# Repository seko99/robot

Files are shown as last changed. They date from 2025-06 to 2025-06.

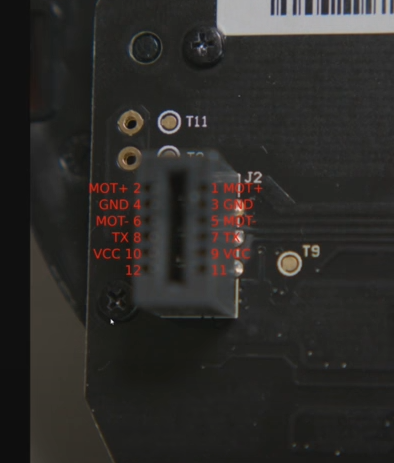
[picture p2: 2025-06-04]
docs/LDS01RR/2024-12-21_15-33.png

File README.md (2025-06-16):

# Robot Control System

Проект системы управления мобильным роботом с дифференциальным приводом на базе Arduino и Orange Pi Zero 3.

## 🤖 Описание

Это комплексная система управления роботом, состоящая из:

- **Arduino микроконтроллеры** для низкоуровневого управления моторами и сенсорами
- **Orange Pi Zero 3** как основной компьютер для высокоуровневой логики
- **ROS2 пакеты** для навигации и управления
- **Ультразвуковые датчики** для определения расстояний
- **Энкодеры** для одометрии
- **Лидар LDS01RR** для 2D сканирования окружения

## 📁 Структура проекта

```
robot/
├── Motors/           # Arduino код для управления моторами
│   ├── Motors.ino   # Основной код управления моторами
│   └── compile.sh   # Скрипт компиляции для Arduino
├── Sensors/          # Arduino код для работы с датчиками
│   ├── Sensors.ino  # Код для ультразвукового датчика
│   └── compile.sh   # Скрипт компиляции для Arduino
├── ROS2/            # ROS2 пакеты для управления роботом
│   ├── robot_bringup/      # Основной пакет запуска
│   ├── robot_odometry/     # Расчет одометрии
│   ├── robot_sonar/        # Обработка ультразвука
│   ├── robot_teleop/       # Телеуправление
│   ├── robot_lidar/ # Драйвер лидара LDS01RR
│   ├── install_packages.sh # Установка пакетов
│   ├── run_robot.sh        # Запуск системы
│   ├── upload_packages.sh  # Загрузка на робота
│   ├── build_on_robot.sh   # Сборка на роботе
│   ├── diagnose_packages.sh # Диагностика пакетов
│   ├── test_package.sh     # Тестирование пакетов
│   ├── PACKAGES_SUMMARY.md # Описание пакетов
│   └── requirements.txt    # Python зависимости
├── 3dprint/         # 3D модели креплений и корпуса (FreeCAD .FCStd)
├── docs/            # Документация и схемы
│   ├── LDS01RR/     # Документация лидара
│   └── *.pdf        # Схемы Orange Pi Zero 3
├── motor_test.py    # Скрипт тестирования моторов
├── serial_read.py   # Утилита чтения Serial данных
├── compile.sh       # Основной скрипт компиляции и загрузки
└── upload_py.sh     # Загрузка Python скриптов
```

## 🐳 Docker контейнеризация

Каждый ROS2 пакет упакован в отдельный Docker контейнер для обеспечения:

- **Изоляции зависимостей** - каждый пакет работает в своем окружении
- **Простоты развертывания** - один команда для запуска
- **Портабильности** - работает на любой системе с Docker
- **Масштабируемости** - легко добавить новые контейнеры

### Особенности реализации

- **Entrypoint скрипты** - корректная инициализация ROS2 окружения в контейнерах
- **Управление устройствами** - проброс USB портов для Serial связи
- **Сетевое взаимодействие** - режим host для DDS коммуникации между контейнерами
- **Автоматическая сборка** - Dockerfile для каждого пакета

## 🔧 Компоненты системы

### Arduino модули

#### Motors (Управление моторами)

- **Файл**: `Motors/Motors.ino`
- **Функции**:
  - Управление двумя DC моторами через драйвер TB6612FNG
  - Чтение энкодеров для одометрии
  - Обработка команд по Serial
- **Пины**:
  - Левый мотор: IN1=5, IN2=6, ENA=9
  - Правый мотор: IN3=7, IN4=8, ENB=10
  - Энкодеры: LEFT_H1=4, LEFT_H2=12, RIGHT_H1=2, RIGHT_H2=3

#### Sensors (Датчики)

- **Файл**: `Sensors/Sensors.ino`
- **Функции**:
  - Ультразвуковой датчик HC-SR04
  - Передача данных о расстояниях
- **Пины**:
  - TRIG=9, ECHO=10

### ROS2 пакеты

Полноценные ROS2 пакеты для автономного управления с поддержкой Docker:

#### 📦 robot_bringup

Основной пакет для запуска всех компонентов робота

#### 📦 robot_odometry

Расчет одометрии на основе данных энкодеров

- **Топики**: `/odom` (nav_msgs/Odometry)
- **Конфигурация**: `config/odometry_params.yaml`
- **Docker**: Собственный контейнер с entrypoint скриптом

#### 📦 robot_sonar

Обработка данных ультразвукового датчика

- **Топики**: `/ultrasonic_sensor/range` (sensor_msgs/Range)
- **Конфигурация**: `config/sonar_params.yaml`
- **Docker**: Собственный контейнер с entrypoint скриптом

#### 📦 robot_teleop

Телеуправление роботом с клавиатуры

- **Подписка**: `/cmd_vel` (geometry_msgs/Twist)
- **Конфигурация**: `config/teleop_params.yaml`
- **Docker**: Собственный контейнер с entrypoint скриптом

#### 📦 robot_lidar

Драйвер для лидара LDS01RR

- **Топики**: `/scan` (sensor_msgs/LaserScan)
- **Функции**: 2D лазерное сканирование для навигации
- **Docker**: Собственный контейнер с entrypoint скриптом

## 🚀 Быстрый старт

### Нативная установка ROS2 пакетов

```bash
cd ROS2/
./install_packages.sh
```

### Запуск через Docker

Каждый ROS2 пакет имеет собственный Docker контейнер для изолированного запуска:

```bash
# Сборка Docker образов для всех пакетов
cd ROS2/robot_teleop/
docker build -t robot_teleop .

cd ../robot_sonar/
docker build -t robot_sonar .

cd ../robot_odometry/
docker build -t robot_odometry .

cd ../robot_lidar/
docker build -t robot_lidar .

# Запуск отдельных пакетов в контейнерах
docker run --rm --device=/dev/ttyUSB0 robot_teleop
docker run --rm --device=/dev/ttyUSB1 robot_sonar
docker run --rm --device=/dev/ttyUSB0 robot_odometry
docker run --rm --device=/dev/ttyUSB2 robot_lidar

# Запуск с сетевым режимом host для ROS2 DDS
docker run --rm --network host --device=/dev/ttyUSB0 robot_teleop
```

### pyhton3 зависимости

```bash
sudo apt install python3-pip
sudo apt install python3-serial
```

### Запуск системы (нативно)

```bash
# Полный запуск всех компонентов
./run_robot.sh full

# Управление с клавиатуры
./run_robot.sh keyboard

# Только одометрия
./run_robot.sh odometry

# С лидаром
./run_robot.sh lidar
```

### Сборка и загрузка на робота

```bash
# Установка пакетов на удаленного робота
cd ROS2/
./upload_packages.sh

# Сборка на роботе
./build_on_robot.sh

# Удаленный запуск
ssh -i ~/.ssh/id_rsa orangepi@192.168.2.141 'cd ~/ros2_ws && ./run_robot.sh full'
```

### Компиляция Arduino кода

#### arduino-cli

```bash
wget https://downloads.arduino.cc/arduino-cli/arduino-cli_latest_Linux_ARM64.tar.gz
tar -xf arduino-cli_latest_Linux_ARM64.tar.gz
sudo mv arduino-cli /usr/local/bin/

/usr/local/bin/arduino-cli version

arduino-cli core update-index
arduino-cli core install arduino:avr

```

```bash
# Основной скрипт (компиляция и загрузка)
./compile.sh

# Для моторов отдельно
cd Motors/
./compile.sh

# Для датчиков отдельно
cd Sensors/
./compile.sh
```

## 🛠 Настройка оборудования

### Подключение Arduino

- **Motors Arduino**: подключить к Orange Pi через USB (/dev/ttyUSB0)
- **Sensors Arduino**: подключить к Orange Pi через USB (/dev/ttyUSB1)
- Настроить правильные порты в ROS2 конфигурации

### Подключение лидара LDS01RR

- **Питание**: 5V
- **Интерфейс**: Serial (115200 baud)
- **Подключение**: к Orange Pi через USB-Serial конвертер

### Схема подключения моторов

```
TB6612FNG драйвер:
- STBY -> Pin 11
- Левый мотор: AIN1->5, AIN2->6, PWMA->9
- Правый мотор: BIN1->7, BIN2->8, PWMB->10
- Энкодеры: подключить к цифровым пинам с прерываниями
```

### Датчики

```
HC-SR04:
- VCC -> 5V
- GND -> GND
- Trig -> Pin 9
- Echo -> Pin 10
```

## 📡 Протокол связи

### Команды для моторов

- `CMD_LEFT_FORWARD (0)` - левый мотор вперед
- `CMD_LEFT_BACKWARD (1)` - левый мотор назад
- `CMD_RIGHT_FORWARD (2)` - правый мотор вперед
- `CMD_RIGHT_BACKWARD (3)` - правый мотор назад
- `CMD_STOP_MOTORS (6)` - остановка всех моторов

### Структуры данных

```cpp
struct Command {
  uint8_t cmd;
  uint8_t value;  // скорость 0-255
};

struct SensorData {
  uint32_t timestamp;
  float left_odometry;
  float right_odometry;
  // ... дополнительные поля
};
```

## 🧪 Тестирование

### Тест моторов

```bash
python3 motor_test.py
```

### Чтение Serial данных

```bash
python3 serial_read.py
```

### Диагностика ROS2

```bash
cd ROS2/
./diagnose_packages.sh
./test_package.sh
```

### Телеуправление

```bash
# Через ROS2 пакет
cd ROS2/
./run_robot.sh keyboard

# Или стандартный teleop_twist_keyboard
ros2 run teleop_twist_keyboard teleop_twist_keyboard
```

### Мониторинг данных

```bash
# Одометрия
ros2 topic echo /odom

# Ультразвук
ros2 topic echo /ultrasonic_sensor/range

# Лидар
ros2 topic echo /scan

# Команды управления
ros2 topic echo /cmd_vel
```

## 📋 Требования

### Программное обеспечение

- **Arduino IDE** или **arduino-cli**
- **ROS2 Jazzy** (на Orange Pi) или **Docker**
- **Python 3.8+**
- **pyserial** для Python скриптов
- **colcon** для сборки ROS2 пакетов (при нативной установке)
- **Docker** (для контейнерного развертывания)

### Аппаратное обеспечение

- **Orange Pi Zero 3** (основной компьютер)
- **Arduino Uno/Nano** x2 (моторы и датчики)
- **TB6612FNG** (драйвер моторов)
- **HC-SR04** (ультразвуковой датчик)
- **LDS01RR** (лидар для 2D сканирования)
- **DC моторы с энкодерами** x2
- **Аккумулятор** и **DC-DC конвертер**

## 🔍 Отладка

### Проверка подключения

```bash
# Список доступных портов
ls /dev/ttyUSB* /dev/ttyACM*

# Тест связи
python3 serial_read.py

# Проверка ROS2 пакетов
ros2 pkg list | grep robot
```

### Логи ROS2

```bash
# Проверка топиков
ros2 topic list

# Мониторинг данных
ros2 topic echo /odom
ros2 topic echo /scan
ros2 topic echo /ultrasonic_sensor/range

# Отправка команд управления
ros2 topic pub /cmd_vel geometry_msgs/msg/Twist \
  "{linear: {x: 0.1}, angular: {z: 0.0}}" --once
```

### Диагностика компонентов

```bash
# Проверка лидара
cd ROS2/robot_lidar/
python3 test_driver.py

# Диагностика всех пакетов
cd ROS2/
./diagnose_packages.sh
```

## 📄 Документация

### 3D модели (`3dprint/`)

В папке содержатся 3D модели компонентов робота в формате **FreeCAD (.FCStd)**:

- Крепления для зарядного устройства
- Крепления для DC-DC конвертера
- Крепления для повербанка
- Крепления для драйвера моторов TB6612FNG
- Крепления для аккумулятора
- Крепления для колес
- Крепление заднего колеса
- Пластина управления питанием
- Стойки 65мм

### Техническая документация (`docs/`)

Дополнительная документация и схемы:

- **Лидар LDS01RR**: datasheet, SDK, примеры ROS интеграции
- **Orange Pi Zero 3**: руководство пользователя и схемы
- Схемы подключения и фотографии сборки

## 🌐 Сетевая настройка

### Cyclone DDS

```bash
sudo apt install ros-jazzy-rmw-cyclonedds-cpp
export RMW_IMPLEMENTATION=rmw_cyclonedx_cpp
echo "export RMW_IMPLEMENTATION=rmw_cyclonedx_cpp" >> ~/.bashrc
```

#### Проверка

##### host1

```bash
sudo apt install ros-jazzy-demo-nodes-cpp
ros2 run demo_nodes_cpp listener
```

##### host2

```bash
sudo apt install ros-jazzy-demo-nodes-cpp
ros2 run demo_nodes_cpp talker
```

### SSH подключение

```bash
# Подключение к роботу
ssh -i ~/.ssh/id_rsa orangepi@192.168.2.141

# Загрузка файлов
scp -i ~/.ssh/id_rsa file.py orangepi@192.168.2.141:~
```

## SLAM

#### Установка

```bash
sudo apt install ros-jazzy-slam-toolbox
```

#### Настройка

Поменять в **/opt/ros/jazzy/share/slam_toolbox/config/mapper_params_online_async.yaml**:

```
base_frame: base_link
```

#### Граф

```bash
ros2 run tf2_tools view_frames
```

#### Запуск

```bash
ros2 launch slam_toolbox online_async_launch.py use_sim_time:=false
```

## Камера

#### Установка

```bash
sudo apt install ros-jazzy-usb-cam
```

#### На роботе

```bash
ros2 run usb_cam usb_cam_node_exe --ros-args -p video_device:="/dev/video1" -p pixel_format:="yuyv"
```

#### На GUI

```bash
ros2 run rqt_image_view rqt_image_view --ros-args -r image:=/image_raw
```

## Удаленное управление

```bash
# Запуск робота
ssh -i ~/.ssh/id_rsa orangepi@192.168.2.141 'cd ~/ros2_ws && ./run_robot.sh full'

# Загрузка пакетов на робота
cd ROS2/
./upload_packages.sh
```

## 🤝 Разработка

### Структура команд

Все команды используют бинарный протокол через Serial (115200 baud).

### Добавление новых сенсоров

1. Добавить код в `Sensors/Sensors.ino`
2. Создать соответствующий ROS2 пакет в `ROS2/`
3. Обновить launch файлы
4. Добавить в `run_robot.sh`

### Создание новых ROS2 пакетов

```bash
cd ROS2/
# Создание нового пакета
ros2 pkg create --build-type ament_python robot_new_package

# Установка
./install_packages.sh
```

## 🚀 Возможности системы

### Автономная навигация

- Одометрия на основе энкодеров
- 2D SLAM с использованием лидара LDS01RR
- Избегание препятствий через ультразвук
- Планирование пути

### Дистанционное управление

- Телеуправление через ROS2 топики
- SSH доступ для удаленной отладки
- Мониторинг состояния в реальном времени

### Модульная архитектура

- Независимые ROS2 пакеты
- Гибкая конфигурация через YAML файлы
- Простое добавление новых сенсоров

## 📞 Поддержка

При возникновении проблем:

1. Проверьте подключение всех компонентов
2. Убедитесь в правильности настройки портов
3. Используйте diagnostic скрипты для проверки ROS2
4. Проверьте логи: `ros2 topic echo /diagnostics`

### Частые проблемы

- **Нет данных с Arduino**: Проверить порты в конфигурации
- **Лидар не работает**: Проверить питание и скорость передачи
- **ROS2 пакеты не найдены**: Выполнить `source install/setup.bash`

---

**Автор**: seko  
**Дата**: 2025  
**Лицензия**: MIT

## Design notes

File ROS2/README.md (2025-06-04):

# ROS2 Robot Control Nodes

Этот проект содержит как отдельные ROS2 ноды, так и полноценные ROS2 пакеты для управления роботом с дифференциальным приводом.

## 🆕 ROS2 Пакеты (рекомендуется)

Новые готовые к установке ROS2 пакеты:

### Быстрая установка и запуск
```bash
# Установка всех пакетов
./install_packages.sh

# Запуск всех компонентов
./run_robot.sh full

# Управление с клавиатуры
./run_robot.sh keyboard
```

### Пакеты
- **robot_odometry** - Пакет одометрии с launch файлами и конфигурацией
- **robot_teleop** - Пакет телеуправления с launch файлами и конфигурацией  
- **robot_sonar** - Пакет сонара с launch файлами и конфигурацией
- **robot_bringup** - Пакет для запуска всех компонентов одной командой

---

## Отдельные ноды (legacy)

Этот пакет содержит ROS2 ноды для управления роботом с дифференциальным приводом.

### Компоненты

- **teleop.py** - Нода для телеуправления роботом через топик `/cmd_vel`
- **odom.py** - Нода для публикации одометрии в топик `/odom`
- **sonar_reader.py** - Нода для чтения данных с ультразвукового датчика

### Способы запуска

#### 1. Быстрый запуск (рекомендуется)

```bash
# Запуск с портами по умолчанию
./start_robot.sh

# Запуск с указанием портов
./start_robot.sh -m /dev/ttyACM0 -s /dev/ttyACM1

# Справка
./start_robot.sh --help
```

#### 2. Простой bash скрипт

```bash
./nodes_start.sh
```

#### 3. ROS2 Launch файлы

```bash
# Простой launch
ros2 launch simple_launch.py

# Полный launch с параметрами
ros2 launch robot_launch.py serial_port:=/dev/ttyUSB0 sonar_port:=/dev/ttyUSB1
```

#### 4. Ручной запуск отдельных нод

```bash
# В отдельных терминалах
python3 teleop.py
python3 odom.py  
python3 sonar_reader.py
```

### Параметры

#### teleop.py
- `serial_port` - Порт для подключения к Arduino моторов (по умолчанию: `/dev/ttyUSB0`)
- `baud_rate` - Скорость передачи данных (по умолчанию: `115200`)
- `max_linear` - Максимальная линейная скорость м/с (по умолчанию: `0.5`)
- `max_angular` - Максимальная угловая скорость рад/с (по умолчанию: `1.57`)
- `wheel_base` - Расстояние между колесами в метрах (по умолчанию: `0.3`)
- `max_motor_speed` - Максимальная скорость мотора PWM (по умолчанию: `255`)

#### odom.py
- `serial_port` - Порт для подключения к Arduino моторов (по умолчанию: `/dev/ttyUSB0`)
- `baud_rate` - Скорость передачи данных (по умолчанию: `115200`)
- `wheel_base` - Расстояние между колесами в метрах (по умолчанию: `0.3`)

#### sonar_reader.py
- `serial_port` - Порт для подключения к Arduino датчиков (по умолчанию: `/dev/ttyUSB1`)

### Топики ROS2

#### Подписка
- `/cmd_vel` (geometry_msgs/Twist) - Команды управления скоростью

#### Публикация
- `/odom` (nav_msgs/Odometry) - Данные одометрии
- `/ultrasonic_sensor/range` (sensor_msgs/Range) - Данные ультразвукового датчика

#### TF фреймы
- `odom` -> `base_link` - Трансформация одометрии

### Зависимости

#### Python пакеты
```bash
pip3 install pyserial
```

#### ROS2 пакеты
- rclpy
- geometry_msgs
- nav_msgs
- sensor_msgs
- tf2_ros

## Аппаратное обеспечение

- Arduino с загруженной прошивкой для моторов (Motors.ino)
- Arduino с загруженной прошивкой для датчиков (Sensors.ino)
- Энкодеры на моторах
- Ультразвуковой датчик

## Устранение неполадок

### Проблемы с портами
1. Проверьте подключение устройств: `ls /dev/tty*`
2. Проверьте права доступа: `sudo usermod -a -G dialout $USER`
3. Перезагрузитесь после добавления в группу

### Проблемы с ROS2
1. Убедитесь что ROS2 установлен: `ros2 --version`
2. Источник environment: `source /opt/ros/humble/setup.bash`

### Отладка
- Увеличьте уровень логирования: `export RCUTILS_LOGGING_SEVERITY=DEBUG`
- Проверьте топики: `ros2 topic list`
- Смотрите данные: `ros2 topic echo /odom`

## Мониторинг

```bash
# Просмотр топиков
ros2 topic list

# Чтение данных одометрии
ros2 topic echo /odom

# Чтение данных сонара
ros2 topic echo /ultrasonic_sensor/range

# Отправка команд движения
ros2 topic pub /cmd_vel geometry_msgs/Twist '{linear: {x: 0.1}, angular: {z: 0.1}}'

# Просмотр TF дерева
ros2 run tf2_tools view_frames
```

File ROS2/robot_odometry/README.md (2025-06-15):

# Robot Odometry Package

ROS2 пакет для публикации одометрии робота и управления движением с интегрированным телеуправлением.

## Описание

Этот пакет объединяет две основные функции:

1. Считывает данные одометрии с Arduino через последовательный порт
2. Обрабатывает команды телеуправления для управления моторами

Интеграция позволяет избежать конфликтов доступа к одному серийному порту.

## Установка

```bash
cd ~/ros2_ws/src
# Скопируйте пакет robot_odometry в src
cd ~/ros2_ws
colcon build --packages-select robot_odometry
source install/setup.bash
```

## Использование

```bash
# Запуск ноды одометрии с интегрированным teleop
ros2 run robot_odometry odometry_node

# Запуск с launch файлом
ros2 launch robot_odometry odometry.launch.py

# Просмотр топиков одометрии
ros2 topic echo /odom

# Отправка команд управления
ros2 topic pub /cmd_vel geometry_msgs/msg/Twist \
  "{linear: {x: 0.1, y: 0.0, z: 0.0}, angular: {x: 0.0, y: 0.0, z: 0.0}}"

# Запуск в режиме симуляции
ros2 run robot_odometry odometry_node --ros-args -p simulation_mode:=true
```

## Параметры

- `serial_port`: Порт Arduino (по умолчанию: /dev/ttyUSB0)
- `baud_rate`: Скорость передачи данных (по умолчанию: 115200)
- `wheel_base`: Расстояние между колесами в метрах (по умолчанию: 0.3)
- `max_linear`: Максимальная линейная скорость в м/с (по умолчанию: 0.5)
- `max_angular`: Максимальная угловая скорость в рад/с (по умолчанию: 1.57)
- `max_motor_speed`: Максимальная скорость мотора PWM (по умолчанию: 255)
- `simulation_mode`: Режим симуляции без подключения к Arduino (по умолчанию: false)

## Топики

### Публикуемые

- `/odom` (nav_msgs/Odometry): Информация об одометрии робота

### Подписываемые

- `/cmd_vel` (geometry_msgs/Twist): Команды управления движением

### TF Frames

- `odom` -> `base_link`: Трансформация положения робота

## Новая архитектура

В обновленной версии функциональность телеуправления интегрирована в одну ноду с одометрией для устранения конфликтов доступа к серийному порту. Это позволяет использовать один Arduino для обеих задач.

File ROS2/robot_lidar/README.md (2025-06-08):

# LDS01RR Lidar ROS2 Driver

ROS2 драйвер для лидара LDS01RR, переписанный с C++ на Python.

## Установка

### Предварительные требования

- ROS2 (Humble/Iron/Jazzy)
- Python 3.8+
- pyserial

### Установка зависимостей

```bash
# Установка Python зависимостей
pip install -r requirements.txt

# Или через apt (Ubuntu)
sudo apt install python3-serial
```

### Сборка и установка пакета

```bash
# Перейти в workspace
cd ~/ros2_ws/src

# Скопировать пакет
cp -r /path/to/lds01rr_lidar_ros2 .

# Собрать пакет
cd ~/ros2_ws
colcon build --packages-select lds01rr_lidar_ros2

# Источник среды
source install/setup.bash
```

## Использование

### Запуск драйвера

```bash
# Базовый запуск
ros2 run lds01rr_lidar_ros2 lidar_node

# Запуск с кастомными параметрами
ros2 run lds01rr_lidar_ros2 lidar_node --ros-args -p port:=/dev/ttyUSB0 -p baud_rate:=115200

# Запуск через launch файл
ros2 launch lds01rr_lidar_ros2 lidar_launch.py

# Запуск с кастомными параметрами через launch
ros2 launch lds01rr_lidar_ros2 lidar_launch.py port:=/dev/ttyUSB0 baud_rate:=115200
```

### Параметры

| Параметр | Тип | По умолчанию | Описание |
| --- | --- | --- | --- |
| `port` | string | `/dev/ttyACM0` | Серийный порт лидара |
| `baud_rate` | int | `115200` | Скорость порта |
| `frame_id` | string | `lidar` | Frame ID для данных лидара  |
| `publish_tf` | bool | `true` | Публиковать ли TF трансформ |
| `parent_frame` | string | `base_link` | Родительский frame для TF |

### Топики

#### Публикуемые топики

- `/scan` (`sensor_msgs/LaserScan`): Данные лазерного сканирования

#### TF Transforms

- `base_link` → `lidar` (если `publish_tf` == true)

## Настройка прав доступа к порту

```bash
# Добавить пользователя в группу dialout
sudo usermod -a -G dialout $USER

# Или установить права на конкретный порт
sudo chmod 666 /dev/ttyACM0
```

## Устранение неполадок

### Ошибка подключения к порту

1. Проверьте, что устройство подключено:

   ```bash
   ls /dev/ttyACM* /dev/ttyUSB*
   ```

2. Проверьте права доступа:

   ```bash
   ls -l /dev/ttyACM0
   ```

3. Проверьте, что порт не используется другим процессом:
   ```bash
   sudo lsof /dev/ttyACM0
   ```

### Нет данных от лидара

1. Проверьте параметры порта (скорость, порт)
2. Проверьте питание лидара
3. Проверьте логи ноды:
   ```bash
   ros2 run lds01rr_lidar_ros2 lidar_node --ros-args --log-level debug
   ```

## Визуализация

```bash
# Запуск RViz2
rviz2

# Добавить LaserScan display
# Topic: /scan
# Fixed Frame: lidar
```

## Лицензия

BSD-3-Clause

## Авторы

- Оригинальный C++ код: Eric Perko, Chad Rockey, iliasam
- Python порт для ROS2: Your Name

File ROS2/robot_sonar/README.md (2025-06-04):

# Robot Sonar Package

ROS2 пакет для чтения данных с ультразвукового датчика через Arduino.

## Описание

Этот пакет считывает данные с ультразвукового датчика через Arduino и публикует их в стандартном формате ROS2 `sensor_msgs/Range`.

## Установка

```bash
cd ~/ros2_ws/src
# Скопируйте пакет robot_sonar в src
cd ~/ros2_ws
colcon build --packages-select robot_sonar
source install/setup.bash
```

## Использование

```bash
# Запуск ноды сонара
ros2 run robot_sonar sonar_node

# Запуск с launch файлом
ros2 launch robot_sonar sonar.launch.py

# Просмотр данных сонара
ros2 topic echo /ultrasonic_sensor/range

# Просмотр частоты публикации
ros2 topic hz /ultrasonic_sensor/range
```

## Параметры

- `serial_port`: Порт Arduino (по умолчанию: /dev/ttyUSB1)
- `baud_rate`: Скорость передачи данных (по умолчанию: 115200)
- `frame_id`: ID фрейма для датчика (по умолчанию: sonar_link)
- `min_range`: Минимальная дальность в метрах (по умолчанию: 0.02)
- `max_range`: Максимальная дальность в метрах (по умолчанию: 4.0)
- `field_of_view`: Угол обзора в радианах (по умолчанию: 0.1)
- `publish_rate`: Частота публикации в Гц (по умолчанию: 10.0)

## Топики

### Публикуемые
- `/ultrasonic_sensor/range` (sensor_msgs/Range): Данные ультразвукового датчика

## Формат данных

Пакет ожидает бинарные данные от Arduino в формате:
- `uint8_t cmd`: Команда (обычно не используется)
- `float distance`: Расстояние в сантиметрах

## Обработка данных

- Данные автоматически преобразуются из сантиметров в метры
- Измерения вне диапазона обрабатываются специальным образом:
  - Слишком близкие: устанавливается значение меньше min_range
  - Слишком далекие: устанавливается infinity

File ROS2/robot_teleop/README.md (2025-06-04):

# Robot Teleop Package

ROS2 пакет для телеуправления роботом через Arduino.

## Описание

Этот пакет принимает команды управления через топик `/cmd_vel` и отправляет соответствующие команды на Arduino для управления моторами робота.

## Установка

```bash
cd ~/ros2_ws/src
# Скопируйте пакет robot_teleop в src
cd ~/ros2_ws
colcon build --packages-select robot_teleop
source install/setup.bash
```

## Использование

```bash
# Запуск ноды телеуправления
ros2 run robot_teleop teleop_node

# Запуск с launch файлом
ros2 launch robot_teleop teleop.launch.py

# Отправка команд управления
ros2 topic pub /cmd_vel geometry_msgs/msg/Twist "{linear: {x: 0.1, y: 0.0, z: 0.0}, angular: {x: 0.0, y: 0.0, z: 0.0}}"

# Использование с клавиатурой (требует установки teleop_twist_keyboard)
ros2 run teleop_twist_keyboard teleop_twist_keyboard
```

## Параметры

- `serial_port`: Порт Arduino (по умолчанию: /dev/ttyUSB0)
- `baud_rate`: Скорость передачи данных (по умолчанию: 115200)
- `max_linear`: Максимальная линейная скорость в м/с (по умолчанию: 0.5)
- `max_angular`: Максимальная угловая скорость в рад/с (по умолчанию: 1.57)
- `wheel_base`: Расстояние между колесами в метрах (по умолчанию: 0.3)
- `max_motor_speed`: Максимальное значение PWM для моторов (по умолчанию: 255)

## Топики

### Подписывается на
- `/cmd_vel` (geometry_msgs/Twist): Команды управления скоростью

## Команды моторов

Пакет отправляет бинарные команды на Arduino:
- `CMD_LEFT_FORWARD` (0): Левый мотор вперед
- `CMD_LEFT_BACKWARD` (1): Левый мотор назад
- `CMD_RIGHT_FORWARD` (2): Правый мотор вперед
- `CMD_RIGHT_BACKWARD` (3): Правый мотор назад
- `CMD_LEFT_STOP` (4): Остановка левого мотора
- `CMD_RIGHT_STOP` (5): Остановка правого мотора
- `CMD_STOP_MOTORS` (6): Остановка всех моторов

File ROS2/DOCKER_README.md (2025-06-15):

# Docker контейнеры для ROS2 нод робота

Этот проект содержит Docker контейнеры для всех ROS2 нод робота с поддержкой ROS2 Jazzy.

## Структура

- `robot_sonar/Dockerfile` - контейнер для ультразвукового сенсора
- `robot_odometry/Dockerfile` - контейнер для одометрии
- `robot_teleop/Dockerfile` - контейнер для телеуправления
- `robot_lidar/Dockerfile` - контейнер для лидара
- `docker-compose.yml` - полная конфигурация со всеми сервисами
- `docker-compose.robot.yml` - упрощенная конфигурация только для основных нод
- `docker-compose.discovery.yml` - конфигурация с ROS Discovery Server для более надежной сетевой связи

## Настройка сети

Для обеспечения видимости ROS2 нод между разными компьютерами в сети:

### 1. Настройка переменных окружения

```bash
# Создайте файл .env в директории ROS2
cp env.example .env

# Отредактируйте .env файл:
# - Установите одинаковый ROS_DOMAIN_ID на всех машинах
# - Укажите IP адрес робота в ROBOT_IP
```

### 2. Настройка на локальной машине (для RViz)

На вашей локальной машине установите те же переменные окружения:

**Вариант A: С CycloneDX (по умолчанию)**

```bash
export ROS_DOMAIN_ID=0  # Тот же, что и на роботе
export RMW_IMPLEMENTATION=rmw_cyclonedx_cpp
export CYCLONEDX_URI='<Discovery><Peers><Peer address="localhost"/><Peer address="192.168.1.100"/></Peers></Discovery>'
export ROS_LOCALHOST_ONLY=0
```

**Вариант B: С Discovery Server (более надежно)**

```bash
export ROS_DOMAIN_ID=0
export RMW_IMPLEMENTATION=rmw_fastrtps_cpp
export ROS_DISCOVERY_SERVER=192.168.1.100:11811  # IP робота
export ROS_LOCALHOST_ONLY=0
```

## Использование

### Запуск всех нод робота (основной режим)

```bash
cd ROS2
# Убедитесь, что .env файл настроен правильно
docker-compose -f docker-compose.robot.yml up -d
```

### Запуск с Discovery Server (рекомендуется для сетевого использования)

```bash
cd ROS2
# Для более надежной сетевой связи
docker-compose -f docker-compose.discovery.yml up -d
```

### Запуск всех нод включая GUI (для разработки)

```bash
cd ROS2
docker-compose up -d
```

### Запуск отдельных нод

```bash
# Только сонар
docker-compose -f docker-compose.robot.yml up robot-sonar

# Только лидар
docker-compose -f docker-compose.robot.yml up lidar

# Только одометрия
docker-compose -f docker-compose.robot.yml up robot-odometry
```

### Остановка всех контейнеров

```bash
docker-compose -f docker-compose.robot.yml down
```

### Просмотр логов

```bash
# Все логи
docker-compose -f docker-compose.robot.yml logs -f

# Логи конкретного сервиса
docker-compose -f docker-compose.robot.yml logs -f robot-sonar
```

## Особенности

### Доступ к устройствам

Все контейнеры имеют доступ к последовательным портам:

- `/dev/ttyUSB0`, `/dev/ttyUSB1`, `/dev/ttyUSB2`, `/dev/ttyUSB3`
- `/dev/ttyACM0`, `/dev/ttyACM1`

### Привилегированный режим

Контейнеры запускаются в привилегированном режиме (`privileged: true`) для обеспечения доступа к устройствам.

### Сеть

Используется `network_mode: host` для обеспечения ROS2 DDS коммуникации между контейнерами.

### Переменные окружения

- `ROS_DOMAIN_ID=0` - домен ROS2 по умолчанию

## Построение образов

Образы строятся автоматически при первом запуске. Для принудительной пересборки:

```bash
docker-compose -f docker-compose.robot.yml build
```

## Отладка

### Вход в контейнер

```bash
docker exec -it robot-sonar bash
```

### Проверка ROS2 нод

```bash
# Список активных нод
docker exec -it robot-sonar ros2 node list

# Список топиков
docker exec -it robot-sonar ros2 topic list

# Просмотр сообщений
docker exec -it robot-sonar ros2 topic echo /ultrasonic_sensor/range
```

### Проверка сетевого соединения

```bash
# На роботе - проверить активные ноды
docker exec -it lidar ros2 node list

# На локальной машине - проверить видимость удаленных нод
ros2 node list

# Проверить топики лидара с локальной машины
ros2 topic list | grep scan
ros2 topic echo /scan

# Запуск RViz на локальной машине
rviz2
```

### Устранение проблем с сетью

Если ноды не видны между машинами:

1. **Проверьте сетевое соединение:**

   ```bash
   ping <ROBOT_IP>
   ```

2. **Проверьте firewall:**

   ```bash
   # На Ubuntu отключите firewall временно для тестирования
   sudo ufw disable
   ```

3. **Проверьте переменные окружения:**

   ```bash
   # На роботе
   docker exec -it lidar printenv | grep ROS

   # На локальной машине
   printenv | grep ROS
   ```

4. **Проверьте мультикаст:**

   ```bash
   # Установите netcat если его нет
   sudo apt install netcat

   # Тест мультикаст (выполните на обеих машинах)
   # На одной машине:
   nc -u 239.255.0.1 7400
   # На другой:
   nc -l -u -p 7400
   ```

## Требования

- Docker >= 20.10
- Docker Compose >= 2.0
- Права доступа к `/dev/tty*` устройствам

## Настройка прав доступа к устройствам

```bash
# Добавить пользователя в группу dialout
sudo usermod -a -G dialout $USER

# Перезагрузить сессию или выйти/войти в систему
```

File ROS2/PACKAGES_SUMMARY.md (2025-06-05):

# ROS2 Packages Installation Summary

## ✅ Созданные пакеты

### 1. robot_odometry
- **Путь**: `/home/seko/Robot/ROS2/robot_odometry/`
- **Описание**: Пакет для публикации одометрии робота
- **Исполняемый файл**: `odometry_node`
- **Топики**: `/odom` (nav_msgs/Odometry)
- **Конфигурация**: `config/odometry_params.yaml`
- **Launch файл**: `launch/odometry.launch.py`

### 2. robot_teleop
- **Путь**: `/home/seko/Robot/ROS2/robot_teleop/`
- **Описание**: Пакет для телеуправления роботом
- **Исполняемый файл**: `teleop_node`
- **Подписка**: `/cmd_vel` (geometry_msgs/Twist)
- **Конфигурация**: `config/teleop_params.yaml`
- **Launch файл**: `launch/teleop.launch.py`

### 3. robot_sonar
- **Путь**: `/home/seko/Robot/ROS2/robot_sonar/`
- **Описание**: Пакет для чтения ультразвукового датчика
- **Исполняемый файл**: `sonar_node`
- **Топики**: `/ultrasonic_sensor/range` (sensor_msgs/Range)
- **Конфигурация**: `config/sonar_params.yaml`
- **Launch файл**: `launch/sonar.launch.py`

### 4. robot_bringup
- **Путь**: `/home/seko/Robot/ROS2/robot_bringup/`
- **Описание**: Пакет для запуска всех компонентов
- **Launch файл**: `launch/robot.launch.py`
- **Зависимости**: robot_odometry, robot_teleop, robot_sonar

## 🛠 Вспомогательные файлы

### Установка и запуск
- **install_packages.sh** - Автоматическая установка всех пакетов в ROS2 workspace
- **run_robot.sh** - Удобный скрипт для запуска компонентов
- **upload_packages.sh** - Загрузка пакетов на удаленного робота
- **requirements.txt** - Python зависимости

### Конфигурация
Каждый пакет содержит:
- `package.xml` - Метаданные пакета и зависимости
- `setup.py` - Конфигурация Python пакета
- `config/*.yaml` - Файлы параметров
- `launch/*.launch.py` - Launch файлы
- `README.md` - Документация

## 🚀 Быстрый старт

```bash
# 1. Установка всех пакетов
cd /home/seko/Robot/ROS2
./install_packages.sh

# 2. Запуск всех компонентов
./run_robot.sh full

# 3. Управление с клавиатуры (в новом терминале)
./run_robot.sh keyboard
```

## 📡 Загрузка на робота

```bash
# Загрузка и установка пакетов на Orange Pi робота
./upload_packages.sh
```

## 🔧 Ручная установка

```bash
# Копирование в ROS2 workspace
cp -r robot_* ~/ros2_ws/src/

# Сборка
cd ~/ros2_ws
colcon build

# Настройка environment
source install/setup.bash
```

## 📊 Использование

### Удалённый запуск по ssh
```bash
ssh -i /home/seko/.ssh/id_rsa orangepi@192.168.2.141 'cd ~/ros2_ws && ./run_robot.sh full'
```

### Отдельные компоненты
```bash
ros2 run robot_odometry odometry_node
ros2 run robot_teleop teleop_node
ros2 run robot_sonar sonar_node
```

### Через launch файлы
```bash
# Все компоненты
ros2 launch robot_bringup robot.launch.py

# Отдельные пакеты
ros2 launch robot_odometry odometry.launch.py
ros2 launch robot_teleop teleop.launch.py
ros2 launch robot_sonar sonar.launch.py
```

### С параметрами
```bash
ros2 launch robot_bringup robot.launch.py \
  odometry_serial_port:=/dev/ttyUSB0 \
  sonar_serial_port:=/dev/ttyUSB1 \
  use_sonar:=false
```

## 🐛 Troubleshooting

### Проверка установки
```bash
# Проверка пакетов
ros2 pkg list | grep robot

# Проверка исполняемых файлов
ros2 pkg executables robot_odometry
ros2 pkg executables robot_teleop  
ros2 pkg executables robot_sonar
```

### Отладка
```bash
# Просмотр топиков
ros2 topic list

# Мониторинг данных
ros2 topic echo /odom
ros2 topic echo /ultrasonic_sensor/range

# Отправка команд
ros2 topic pub /cmd_vel geometry_msgs/msg/Twist \
  "{linear: {x: 0.1}, angular: {z: 0.0}}" --once
```

## ✨ Преимущества новых пакетов

1. **Стандартная структура ROS2** - Соответствует best practices
2. **Легкая установка** - Автоматические скрипты установки
3. **Параметризация** - Гибкая настройка через параметры и launch файлы
4. **Документация** - README файлы для каждого пакета
5. **Конфигурация** - YAML файлы для настройки параметров
6. **Удобный запуск** - Launch файлы для различных сценариев
7. **Готовность к дистрибуции** - Можно легко поделиться с другими разработчиками

Все файлы готовы к использованию! 🎉

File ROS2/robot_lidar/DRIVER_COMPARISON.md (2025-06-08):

# Сравнение драйверов LDS01RR v1 и v2

## Основные различия

### Драйвер v1 (lds01rr_driver.py)

- **Протокол**: Использует заголовки пакетов `0xE7 0x7E`
- **Базовый код**: Основан на более старой реализации
- **Структура пакетов**: 34-байтовые пакеты измерений
- **Синхронизация**: Простая последовательность синхронизации
- **Проблема**: Возможно использует устаревший протокол

### Драйвер v2 (lds01rr_driver_v2.py)

- **Протокол**: Использует заголовки `0xAA` (информация) и `0xFA` (измерения)
- **Базовый код**: Основан на LDS.c (оригинальная C реализация)
- **Структура пакетов**:
  - Информационные пакеты: 85 байт
  - Измерительные пакеты: 22 байта
- **Синхронизация**: Полная реализация с escape-последовательностями
- **Контрольные суммы**: Правильная проверка целостности данных

## Протокольные отличия

### v1 Protocol

```
Sync: 0xE7 0x7E
Packet size: 34 bytes
Structure: [sync][size][data...]
```

### v2 Protocol

```
Info packets: 0xAA [data...] (85 bytes total)
Measurement packets: 0xFA [angle][speed][4x measurements] (22 bytes total)
Escape sequences: 0xA9 0x00 -> 0xA9, 0xA9 0x01 -> 0xAA
Checksums: Different algorithms for info vs measurement packets
```

## Особенности v2

1. **Правильная обработка escape-последовательностей**

   - 0xA9 0x00 представляет байт 0xA9
   - 0xA9 0x01 представляет байт 0xAA

2. **Корректные контрольные суммы**

   - Информационные пакеты: простая сумма 16-битных слов
   - Измерительные пакеты: циклический сдвиг с накоплением

3. **Правильная структура данных измерений**

   - Каждый пакет содержит индекс угла и скорость мотора
   - 4 точки измерения на пакет
   - Правильное вычисление углов

4. **Контроль скорости мотора**
   - Извлечение данных о скорости из пакетов
   - Публикация скорости в отдельном топике

## Использование v2

### Тестирование драйвера

```bash
cd ~/Robot/ROS2/lds01rr_lidar_ros2
python3 -m lds01rr_lidar_ros2.test_driver_v2
```

### Запуск ROS2 ноды

```bash
# Сборка пакета
colcon build --packages-select lds01rr_lidar_ros2

# Запуск ноды v2
ros2 run lds01rr_lidar_ros2 lidar_node_v2

# Или с launch файлом
ros2 launch lds01rr_lidar_ros2 lds01rr_v2.launch.py serial_port:=/dev/ttyUSB0
```

### Параметры

- `serial_port`: Последовательный порт (по умолчанию /dev/ttyUSB0)
- `baud_rate`: Скорость передачи (по умолчанию 115200)
- `frame_id`: ID фрейма для данных лидара
- `publish_rate`: Частота публикации в Гц

### Топики

- `/scan`: sensor_msgs/LaserScan - данные сканирования
- `/lidar_speed`: std_msgs/Float32 - скорость мотора в RPM

## Рекомендации

1. **Используйте v2** если текущий драйвер не работает корректно
2. **Проверьте последовательный порт** - может быть /dev/ttyUSB0 или /dev/ttyS5
3. **Мониторьте топик скорости** для контроля работы мотора лидара
4. **Проверяйте логи** на наличие ошибок контрольных сумм

## Отладка

Если v2 тоже не работает:

1. Проверьте подключение лидара
2. Убедитесь в правильности последовательного порта
3. Проверьте скорость передачи данных
4. Возможно, ваш лидар использует другой протокол

Для получения подробной информации используйте:

```bash
ros2 run lds01rr_lidar_ros2 test_driver_v2
```

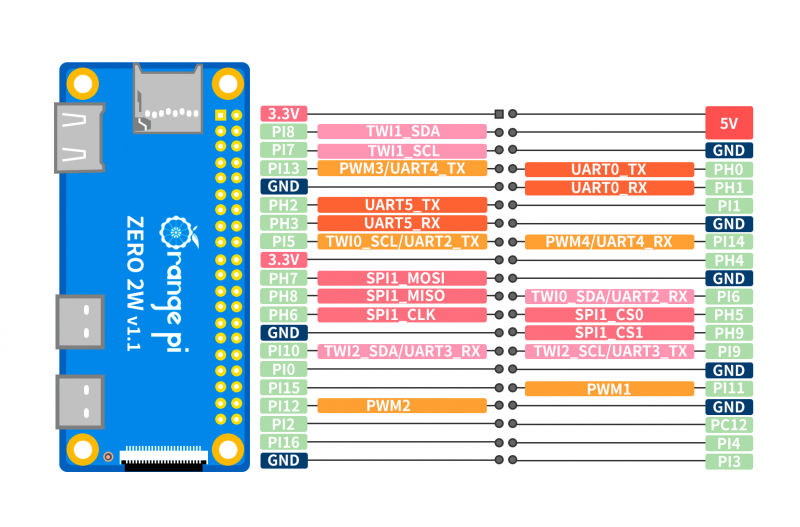
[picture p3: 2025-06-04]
docs/800px-Zero2w-img7.png

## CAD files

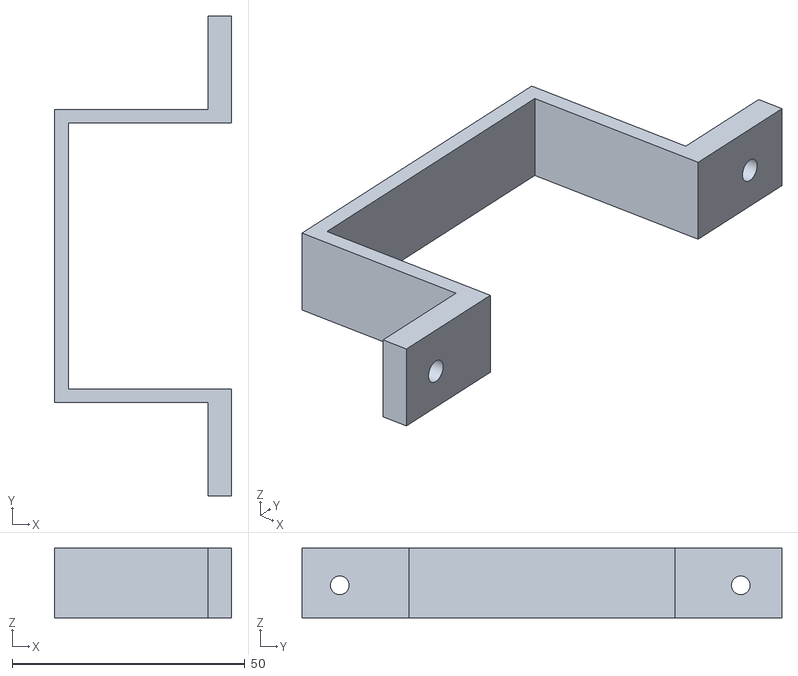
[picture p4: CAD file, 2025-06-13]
3dprint/STL/крепёж аккум-Body.stl
38.0 x 103.0 x 15.0

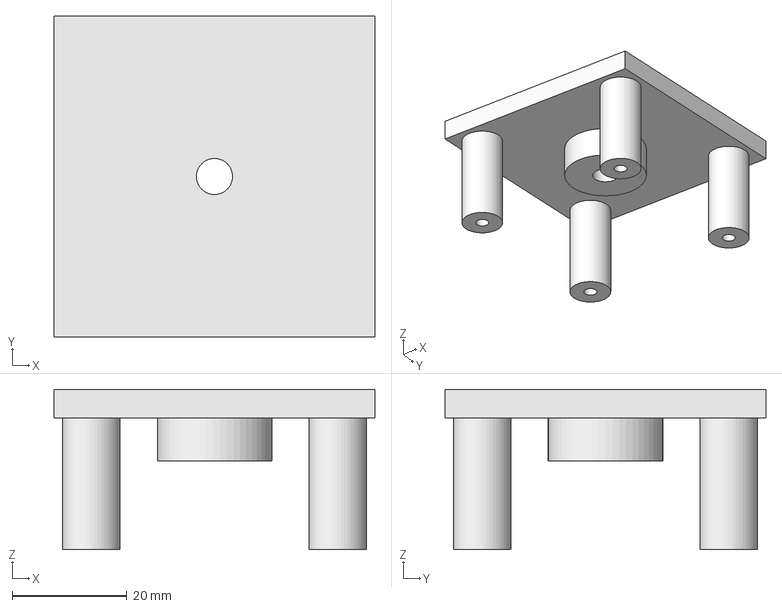
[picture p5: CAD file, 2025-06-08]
3dprint/крепёж заднего колеса.FCStd
56.0 x 56.0 x 28.0 mm

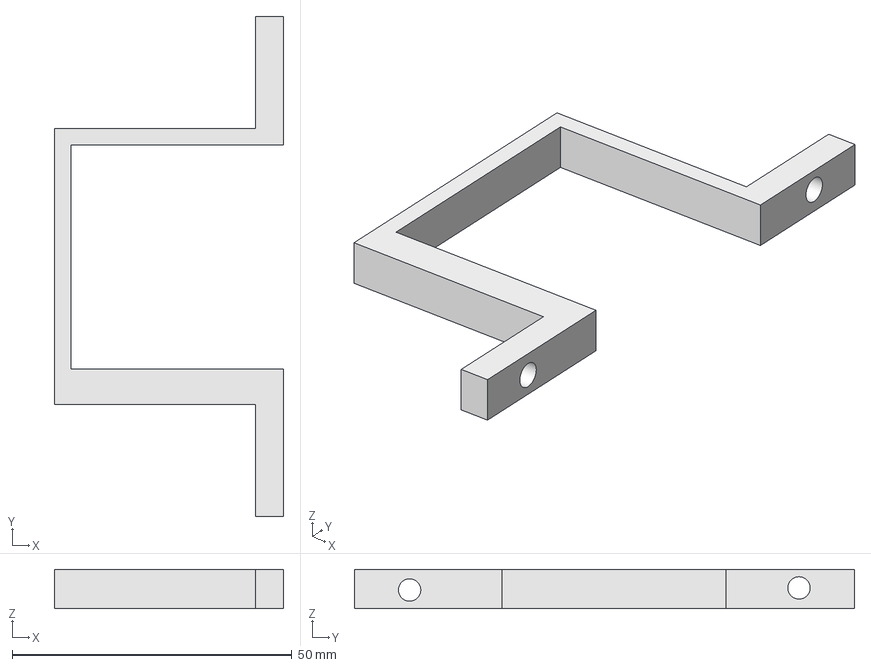
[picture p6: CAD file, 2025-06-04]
3dprint/крепёж колеса.FCStd
41.0 x 89.4 x 7.00 mm

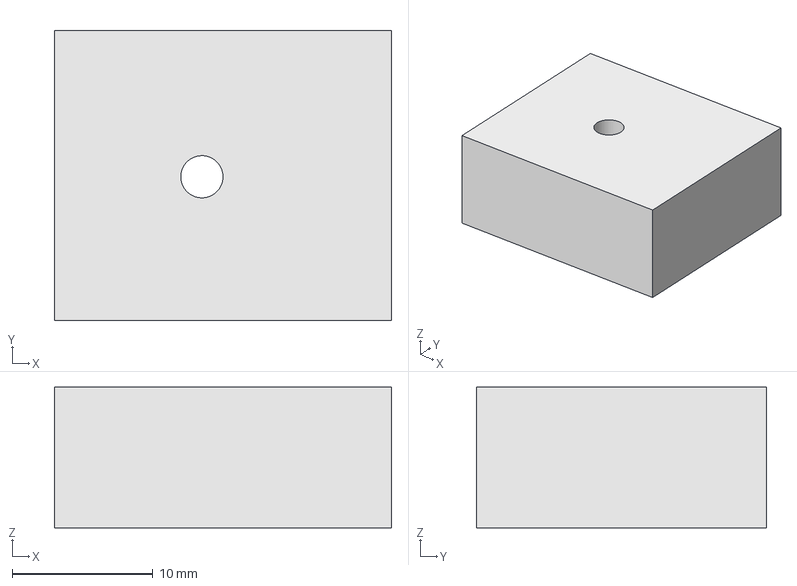
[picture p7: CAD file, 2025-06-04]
3dprint/крепёж TB6612FNG.FCStd
23.9 x 20.6 x 10.0 mm

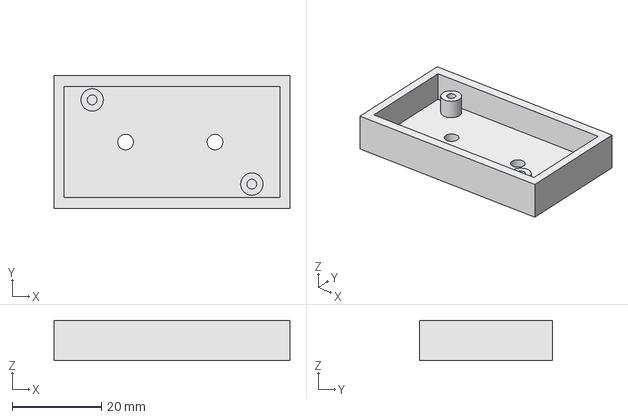
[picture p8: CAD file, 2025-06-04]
3dprint/крепёж DC-DC.FCStd
52.8 x 29.8 x 9.00 mm

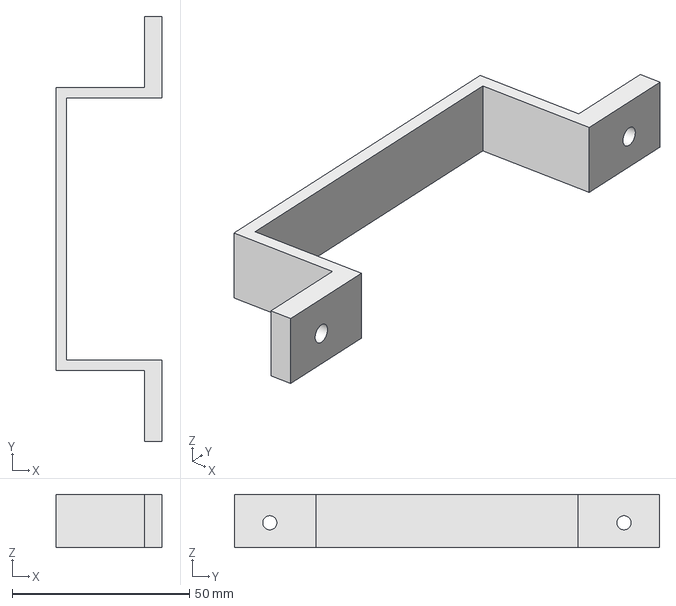
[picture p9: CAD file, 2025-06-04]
3dprint/крепёж powerbank.FCStd
30.0 x 120.0 x 15.0 mm

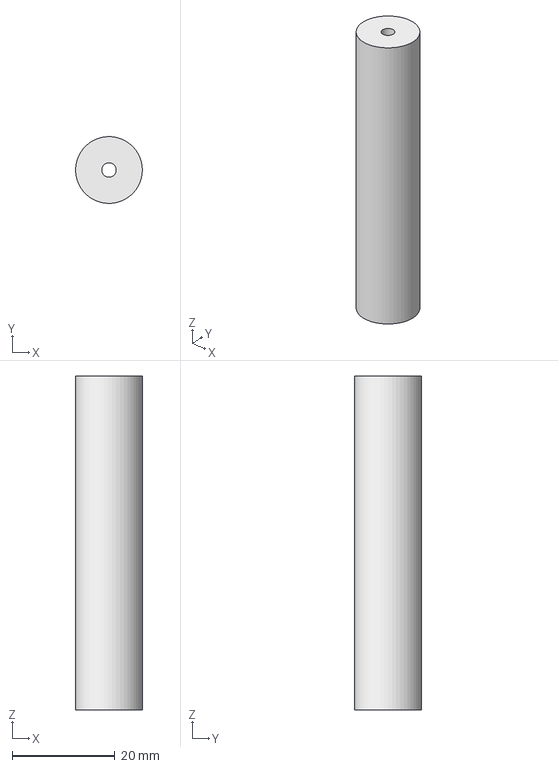
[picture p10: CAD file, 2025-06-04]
3dprint/стойка 65мм.FCStd
13.0 x 13.0 x 65.0 mm

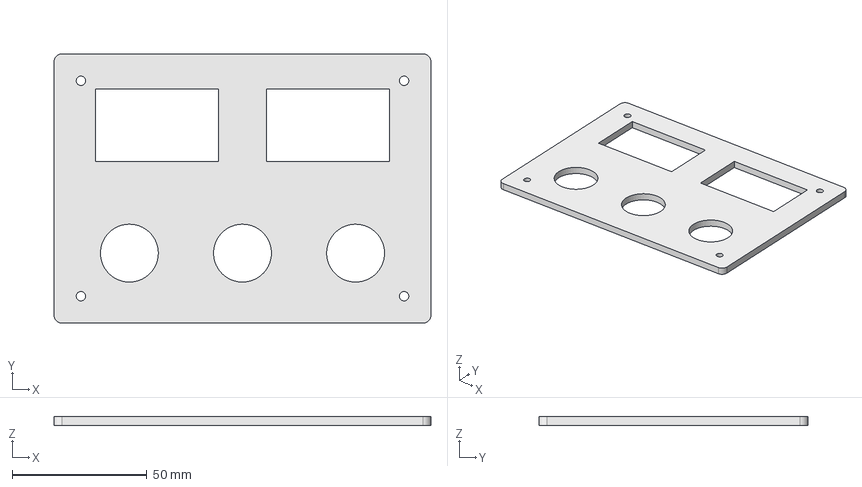
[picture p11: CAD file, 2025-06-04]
3dprint/пластина управления питанием.FCStd
140.0 x 100.0 x 3.50 mm

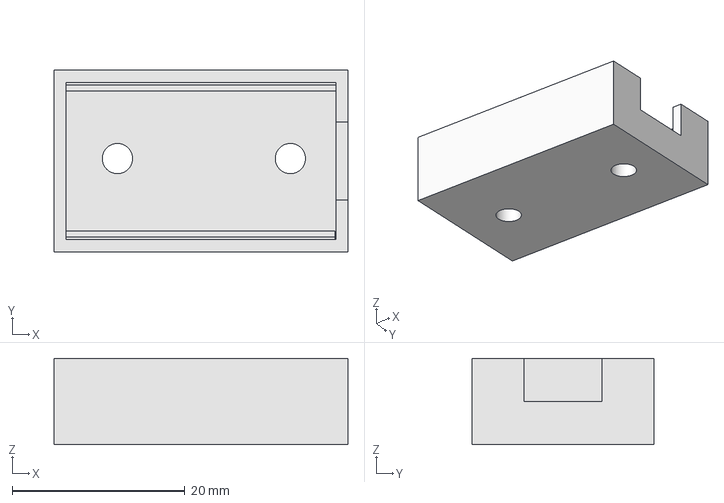
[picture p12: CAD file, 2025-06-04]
3dprint/крепёж charger.FCStd
34.0 x 21.0 x 10.0 mm

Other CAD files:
3dprint/крепёж аккум.FCStd

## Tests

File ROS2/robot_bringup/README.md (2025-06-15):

# Robot Bringup Package

ROS2 пакет для запуска всех компонентов робота одной командой.

## Описание

Этот пакет объединяет запуск всех основных компонентов робота:

- Одометрия с интегрированным телеуправлением (`robot_odometry`)
- Ультразвуковой датчик (`robot_sonar`)
- Лидар LDS01RR (`robot_lidar`)

## Установка

```bash
cd ~/ros2_ws/src
# Скопируйте все пакеты robot_* в src
cd ~/ros2_ws
colcon build
source install/setup.bash
```

## Использование

### Запуск всех компонентов

```bash
# Запуск с настройками по умолчанию
ros2 launch robot_bringup robot.launch.py

# Запуск с кастомными портами
ros2 launch robot_bringup robot.launch.py \
  odometry_serial_port:=/dev/ttyUSB0 \
  sonar_serial_port:=/dev/ttyUSB1 \
  lidar_serial_port:=/dev/ttyS5

# Запуск без сонара и лидара
ros2 launch robot_bringup robot.launch.py use_sonar:=false use_lidar:=false

# Запуск с настроенными скоростями
ros2 launch robot_bringup robot.launch.py \
  max_linear:=0.8 \
  max_angular:=2.0

# Запуск в режиме симуляции (без подключения к Arduino)
ros2 launch robot_bringup robot.launch.py simulation_mode:=true
```

### Проверка работы

```bash
# Просмотр активных топиков
ros2 topic list

# Проверка одометрии
ros2 topic echo /odom

# Проверка сонара
ros2 topic echo /ultrasonic_sensor/range

# Проверка лидара
ros2 topic echo /scan

# Отправка команд управления
ros2 topic pub /cmd_vel geometry_msgs/msg/Twist \
  "{linear: {x: 0.1, y: 0.0, z: 0.0}, angular: {x: 0.0, y: 0.0, z: 0.0}}"
```

## Параметры

### Серийные порты

- `odometry_serial_port`: Порт для Arduino с одометрией и моторами (по умолчанию: /dev/ttyUSB0)
- `sonar_serial_port`: Порт для Arduino с сонаром (по умолчанию: /dev/ttyUSB1)
- `lidar_serial_port`: Порт для лидара LDS01RR (по умолчанию: /dev/ttyS5)

### Физические параметры робота

- `wheel_base`: Расстояние между колесами в метрах (по умолчанию: 0.3)

### Параметры управления

- `max_linear`: Максимальная линейная скорость в м/с (по умолчанию: 0.5)
- `max_angular`: Максимальная угловая скорость в рад/с (по умолчанию: 1.57)

### Флаги включения компонентов

- `use_sonar`: Включать ли сонар (по умолчанию: true)
- `use_lidar`: Включать ли лидар (по умолчанию: true)
- `simulation_mode`: Запуск в режиме симуляции без подключения к Arduino (по умолчанию: false)

## Топики

### Публикуемые топики

- `/odom` (nav_msgs/Odometry) - данные одометрии
- `/ultrasonic_sensor/range` (sensor_msgs/Range) - данные ультразвукового датчика
- `/scan` (sensor_msgs/LaserScan) - данные лидара

### Подписываемые топики

- `/cmd_vel` (geometry_msgs/Twist) - команды управления скоростью (обрабатываются нодой odometry)

## Зависимости

Этот пакет требует установки следующих пакетов:

- `robot_odometry` (с интегрированным телеуправлением)
- `robot_sonar`
- `robot_lidar`

## Изменения в архитектуре

В новой версии логика телеуправления интегрирована в пакет `robot_odometry` для избежания конфликтов доступа к одному и тому же серийному порту. Теперь одна нода обрабатывает и команды движения, и данные одометрии.

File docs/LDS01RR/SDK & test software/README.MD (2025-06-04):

1.  tar zxvf lds_install.tar.gz -C .
2.  cd ./install/lds_node/script/
3.  sudo ./script.sh  (if failed, sudo chmod +x script.sh，then try again!)
4.  cd ../..
5.  source setup.bash
6.  cd lds_node/launch/
7.  roslaunch lds_node.launch

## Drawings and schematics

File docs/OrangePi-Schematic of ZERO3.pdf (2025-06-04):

D | D

# 1.Note that the voltage of SOC GPIO must matches the

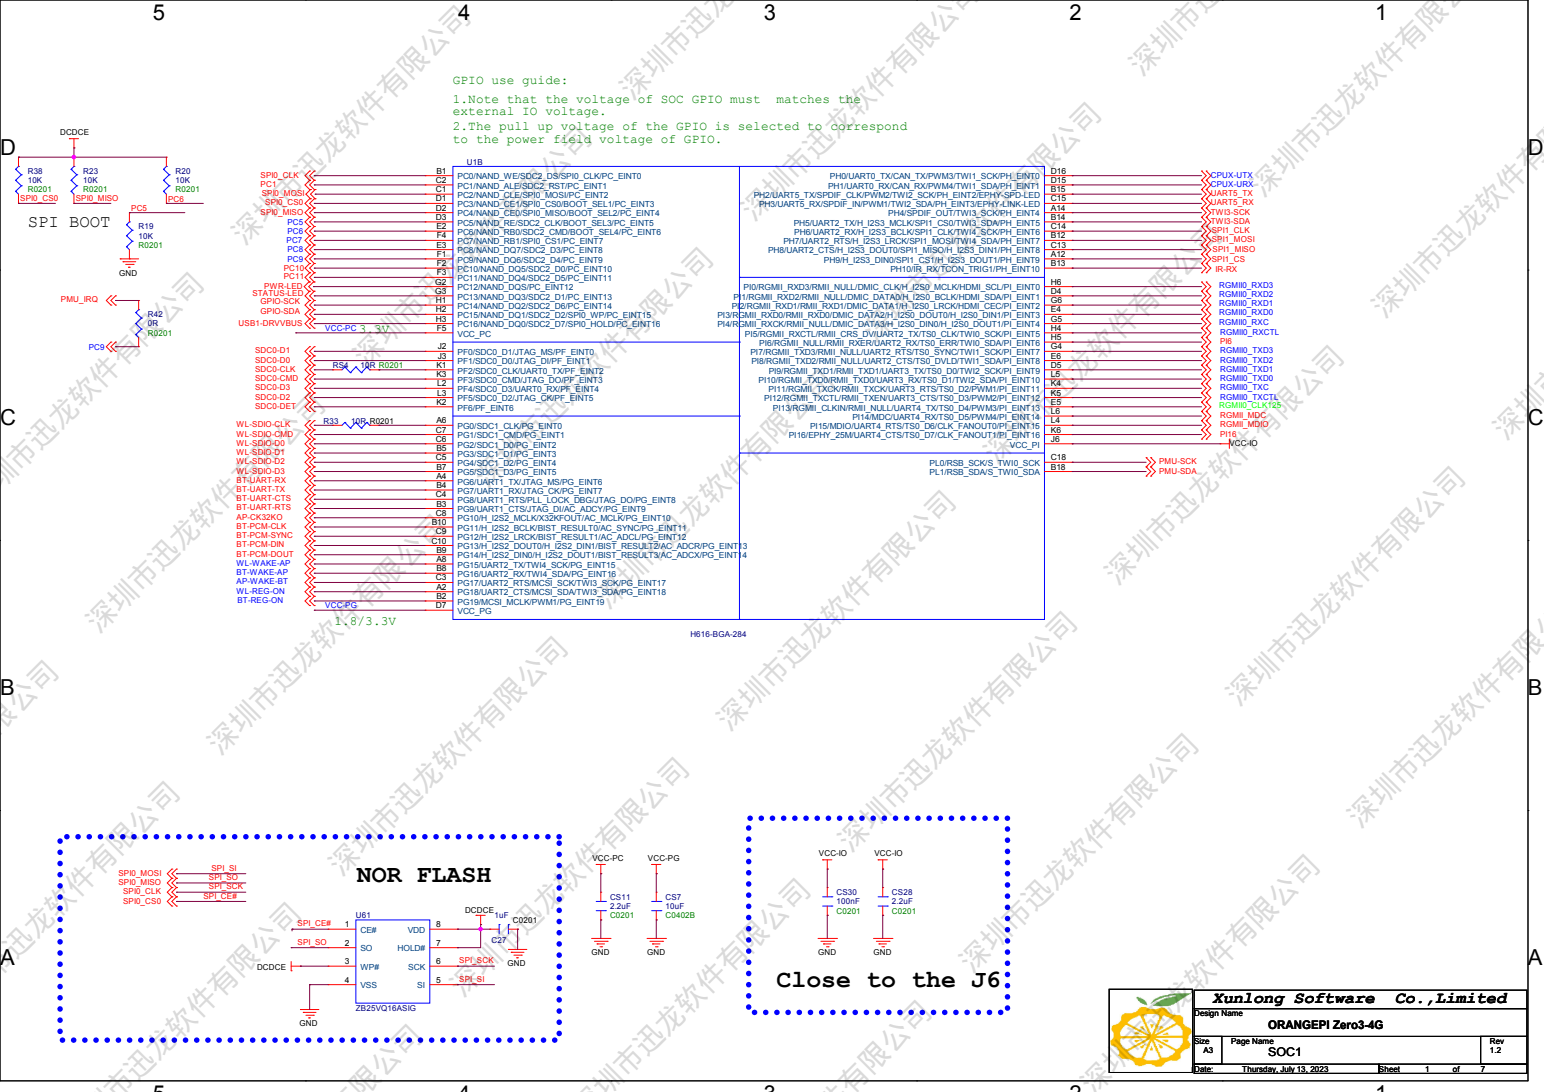
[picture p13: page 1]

深圳市迅龙软件有限公司 深圳市迅龙软件有限公司 深圳市迅龙软件有限公司 深圳市迅龙软件有限公司 深圳市迅龙软件有限公司 深圳市迅龙软件有限公司 深圳市迅龙软件有限公司 深圳市迅龙软件有限公司 深圳市迅龙软件有限公司 深圳市迅龙软件有限公司 深圳市迅龙软件有限公司 深圳市迅龙软件有限公司 深圳市迅龙软件有限公司 深圳市迅龙软件有限公司 深圳市迅龙软件有限公司 深圳市迅龙软件有限公司 深圳市迅龙软件有限公司 深圳市迅龙软件有限公司 深圳市迅龙软件有限公司 深圳市迅龙软件有限公司 深圳市迅龙软件有限公司 深圳市迅龙软件有限公司 深圳市迅龙软件有限公司 深圳市迅龙软件有限公司 深圳市迅龙软件有限公司 深圳市迅龙软件有限公司 深圳市迅龙软件有限公司 深圳市迅龙软件有限公司 深圳市迅龙软件有限公司 深圳市迅龙软件有限公司 深圳市迅龙软件有限公司 深圳市迅龙软件有限公司 深圳市迅龙软件有限公司 深圳市迅龙软件有限公司 深圳市迅龙软件有限公司 深圳市迅龙软件有限公司 深圳市迅龙软件有限公司 深圳市迅龙软件有限公司 深圳市迅龙软件有限公司 深圳市迅龙软件有限公司

GPIO use guide:
external IO voltage.
2.The pull up voltage of the GPIO is selected to correspond
to the power field voltage of GPIO.

Xunlong Software Co.,Limited

D | D

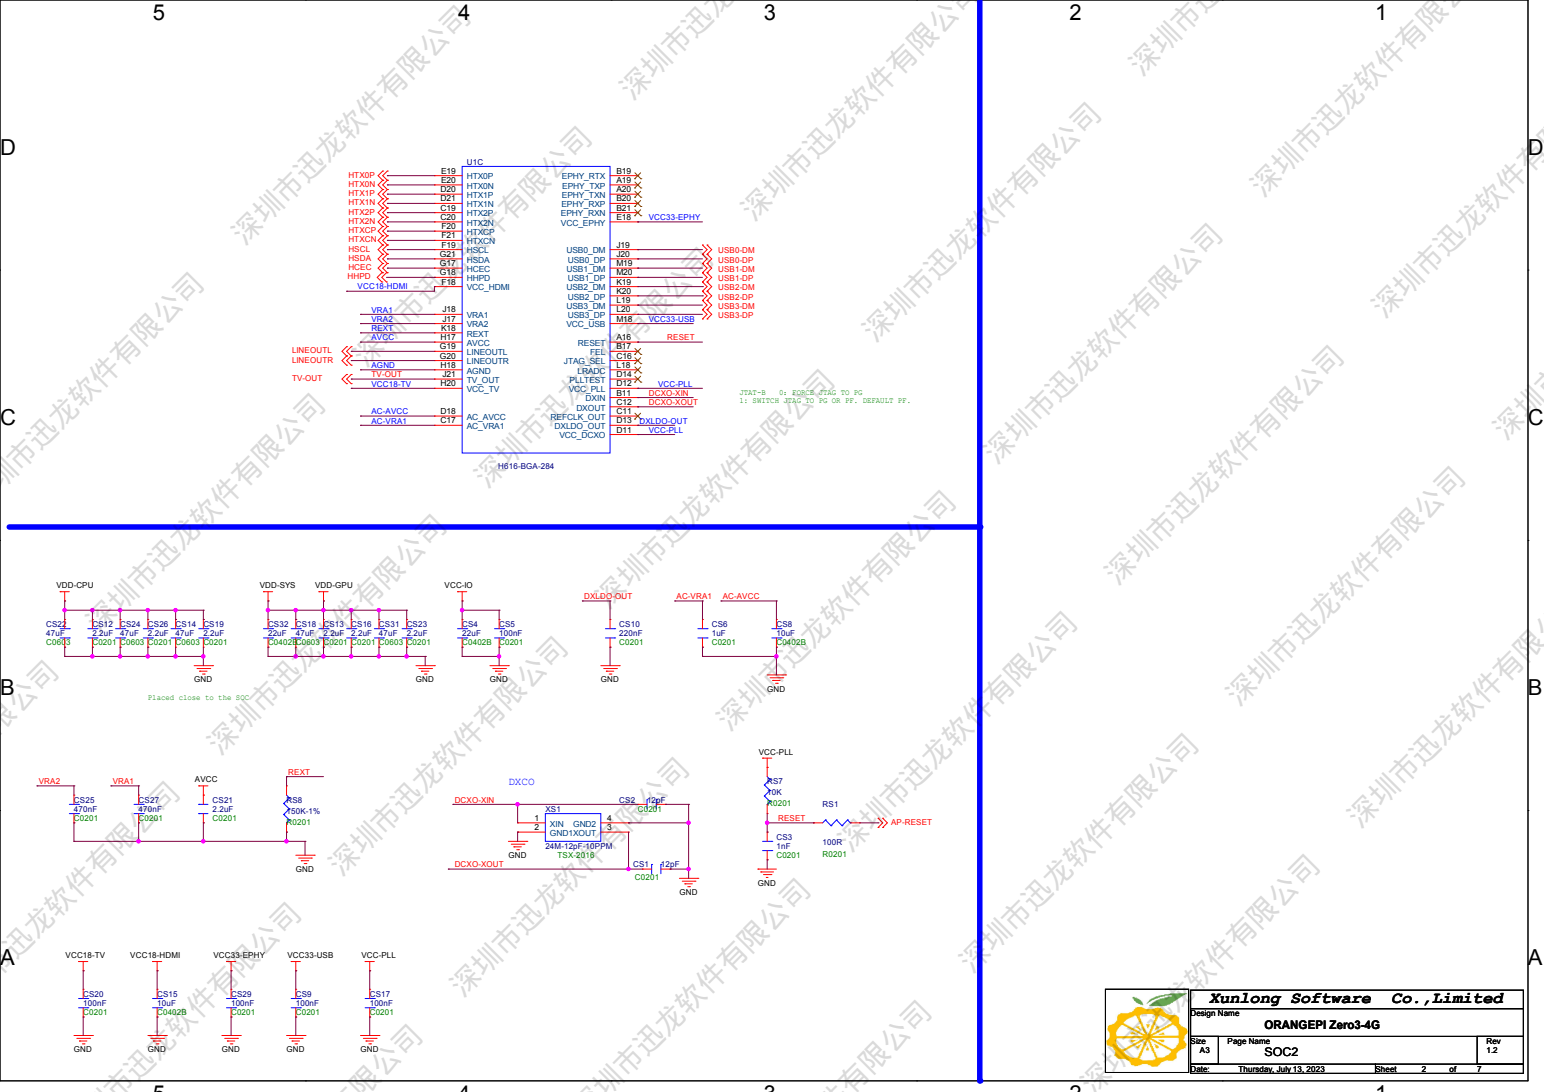
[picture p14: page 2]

深圳市迅龙软件有限公司 深圳市迅龙软件有限公司 深圳市迅龙软件有限公司 深圳市迅龙软件有限公司 深圳市迅龙软件有限公司 深圳市迅龙软件有限公司 深圳市迅龙软件有限公司 深圳市迅龙软件有限公司 深圳市迅龙软件有限公司 深圳市迅龙软件有限公司 深圳市迅龙软件有限公司 深圳市迅龙软件有限公司 深圳市迅龙软件有限公司 深圳市迅龙软件有限公司 深圳市迅龙软件有限公司 深圳市迅龙软件有限公司 深圳市迅龙软件有限公司 深圳市迅龙软件有限公司 深圳市迅龙软件有限公司 深圳市迅龙软件有限公司 深圳市迅龙软件有限公司 深圳市迅龙软件有限公司 深圳市迅龙软件有限公司 深圳市迅龙软件有限公司 深圳市迅龙软件有限公司 深圳市迅龙软件有限公司 深圳市迅龙软件有限公司 深圳市迅龙软件有限公司 深圳市迅龙软件有限公司 深圳市迅龙软件有限公司 深圳市迅龙软件有限公司 深圳市迅龙软件有限公司 深圳市迅龙软件有限公司 深圳市迅龙软件有限公司 深圳市迅龙软件有限公司 深圳市迅龙软件有限公司 深圳市迅龙软件有限公司 深圳市迅龙软件有限公司 深圳市迅龙软件有限公司 深圳市迅龙软件有限公司

JTAT-B 0：FORCE JTAG TO PG
1: SWITCH JTAG TO PG OR PF. DEFAULT PF.

Placed close to the SOC

Xunlong Software Co.,Limited

D | D

# LPDDR4

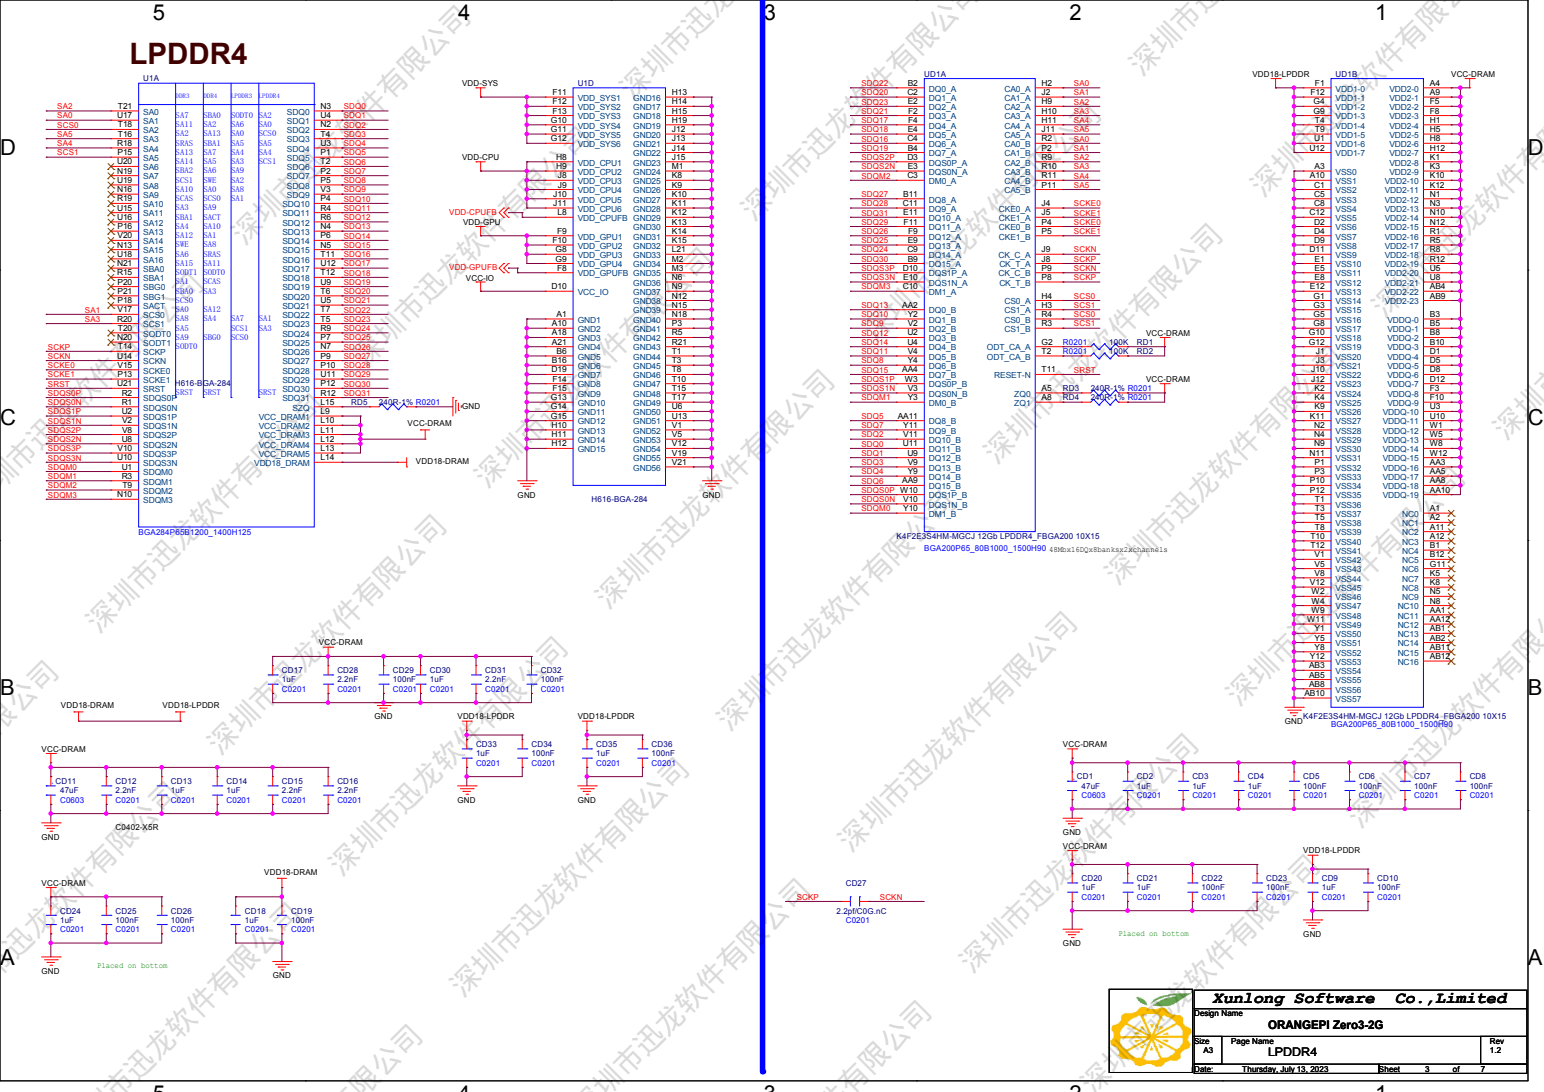
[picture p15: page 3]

深圳市迅龙软件有限公司 深圳市迅龙软件有限公司 深圳市迅龙软件有限公司 深圳市迅龙软件有限公司 深圳市迅龙软件有限公司 深圳市迅龙软件有限公司 深圳市迅龙软件有限公司 深圳市迅龙软件有限公司 深圳市迅龙软件有限公司 深圳市迅龙软件有限公司 深圳市迅龙软件有限公司 深圳市迅龙软件有限公司 深圳市迅龙软件有限公司 深圳市迅龙软件有限公司 深圳市迅龙软件有限公司 深圳市迅龙软件有限公司 深圳市迅龙软件有限公司 深圳市迅龙软件有限公司 深圳市迅龙软件有限公司 深圳市迅龙软件有限公司 深圳市迅龙软件有限公司 深圳市迅龙软件有限公司 深圳市迅龙软件有限公司 深圳市迅龙软件有限公司 深圳市迅龙软件有限公司 深圳市迅龙软件有限公司 深圳市迅龙软件有限公司 深圳市迅龙软件有限公司 深圳市迅龙软件有限公司 深圳市迅龙软件有限公司 深圳市迅龙软件有限公司 深圳市迅龙软件有限公司 深圳市迅龙软件有限公司 深圳市迅龙软件有限公司 深圳市迅龙软件有限公司 深圳市迅龙软件有限公司 深圳市迅龙软件有限公司 深圳市迅龙软件有限公司 深圳市迅龙软件有限公司 深圳市迅龙软件有限公司

Xunlong Software Co.,Limited

# TPYE-C

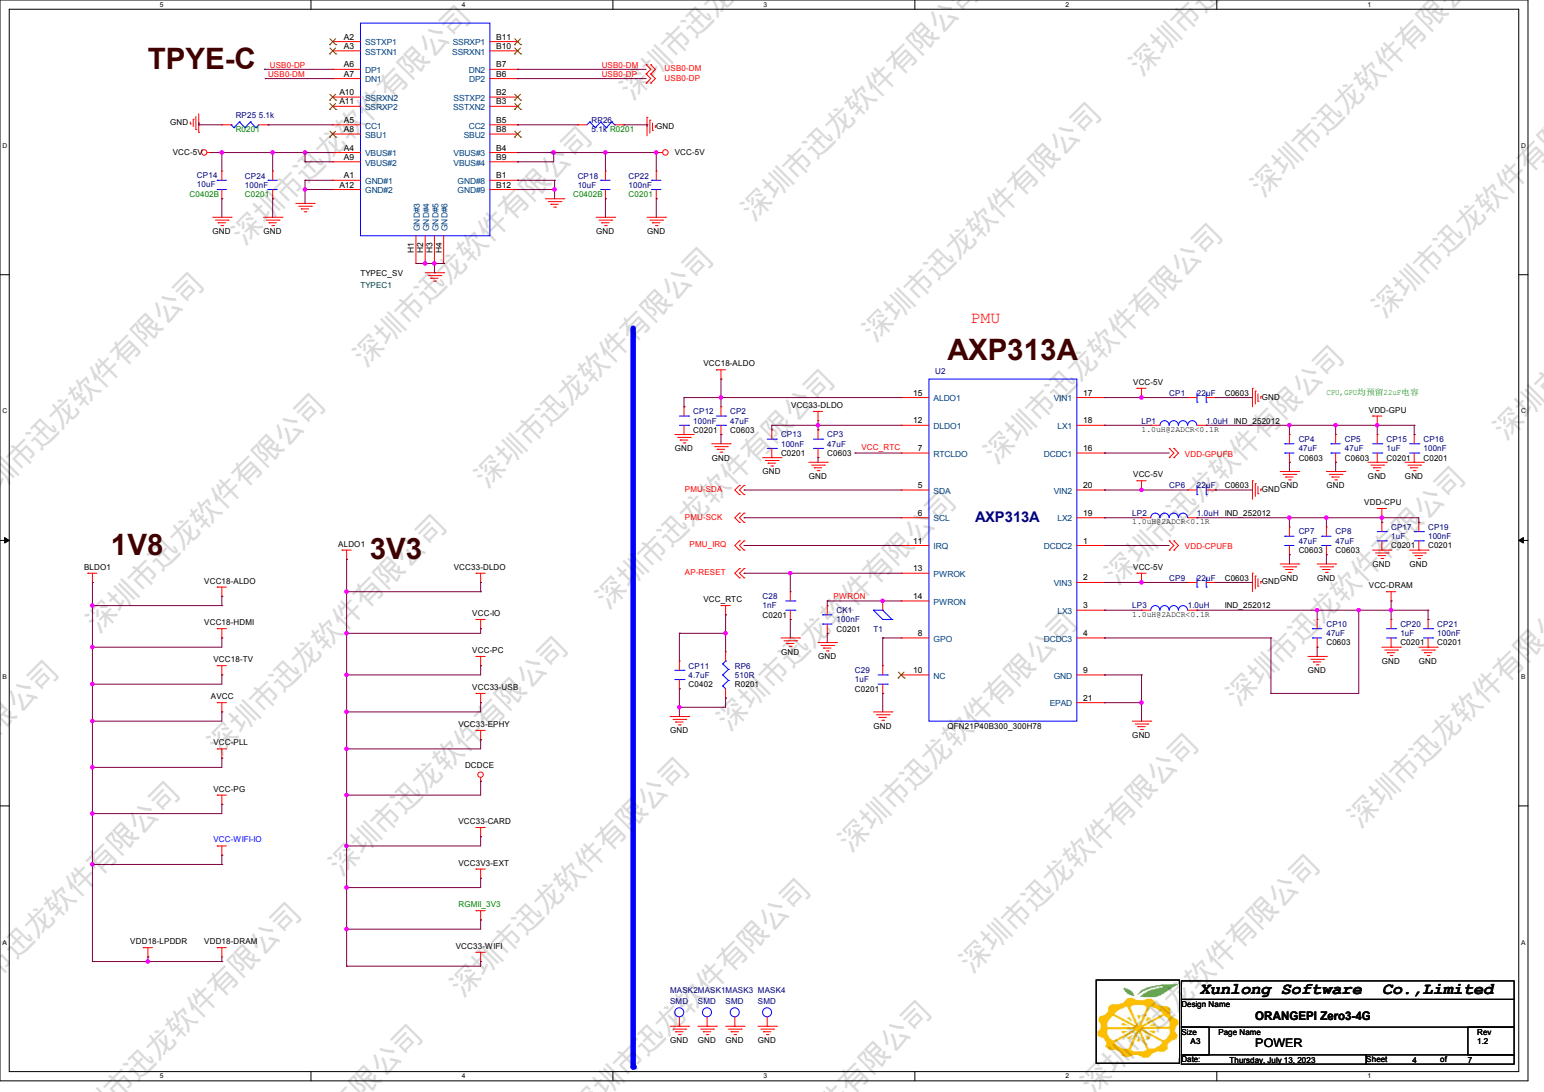
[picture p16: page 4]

深圳市迅龙软件有限公司 深圳市迅龙软件有限公司 深圳市迅龙软件有限公司 深圳市迅龙软件有限公司 深圳市迅龙软件有限公司 深圳市迅龙软件有限公司 深圳市迅龙软件有限公司 深圳市迅龙软件有限公司 深圳市迅龙软件有限公司 深圳市迅龙软件有限公司 深圳市迅龙软件有限公司 深圳市迅龙软件有限公司 深圳市迅龙软件有限公司 深圳市迅龙软件有限公司 深圳市迅龙软件有限公司 深圳市迅龙软件有限公司 深圳市迅龙软件有限公司 深圳市迅龙软件有限公司 深圳市迅龙软件有限公司 深圳市迅龙软件有限公司 深圳市迅龙软件有限公司 深圳市迅龙软件有限公司 深圳市迅龙软件有限公司 深圳市迅龙软件有限公司 深圳市迅龙软件有限公司 深圳市迅龙软件有限公司 深圳市迅龙软件有限公司 深圳市迅龙软件有限公司 深圳市迅龙软件有限公司 深圳市迅龙软件有限公司 深圳市迅龙软件有限公司 深圳市迅龙软件有限公司 深圳市迅龙软件有限公司 深圳市迅龙软件有限公司 深圳市迅龙软件有限公司 深圳市迅龙软件有限公司 深圳市迅龙软件有限公司 深圳市迅龙软件有限公司 深圳市迅龙软件有限公司 深圳市迅龙软件有限公司

Xunlong Software Co.,Limited

D | D

# T CARD

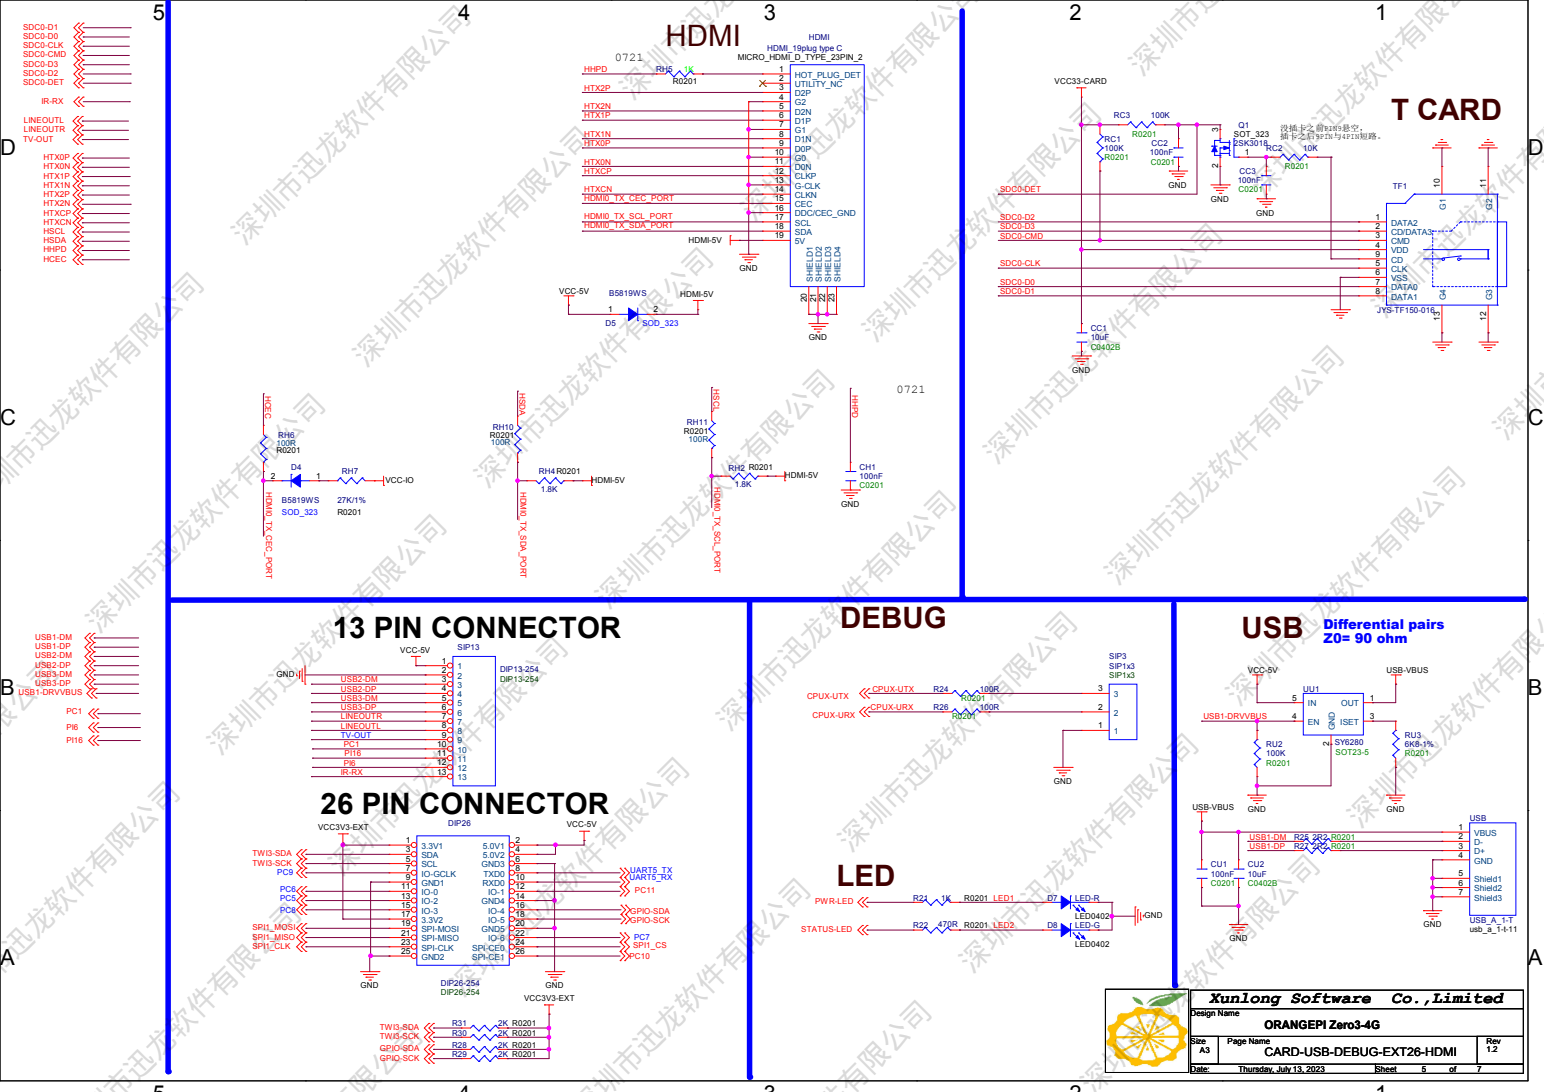
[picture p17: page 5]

深圳市迅龙软件有限公司 深圳市迅龙软件有限公司 深圳市迅龙软件有限公司 深圳市迅龙软件有限公司 深圳市迅龙软件有限公司 深圳市迅龙软件有限公司 深圳市迅龙软件有限公司 深圳市迅龙软件有限公司 深圳市迅龙软件有限公司 深圳市迅龙软件有限公司 深圳市迅龙软件有限公司 深圳市迅龙软件有限公司 深圳市迅龙软件有限公司 深圳市迅龙软件有限公司 深圳市迅龙软件有限公司 深圳市迅龙软件有限公司 深圳市迅龙软件有限公司 深圳市迅龙软件有限公司 深圳市迅龙软件有限公司 深圳市迅龙软件有限公司 深圳市迅龙软件有限公司 深圳市迅龙软件有限公司 深圳市迅龙软件有限公司 深圳市迅龙软件有限公司 深圳市迅龙软件有限公司 深圳市迅龙软件有限公司 深圳市迅龙软件有限公司 深圳市迅龙软件有限公司 深圳市迅龙软件有限公司 深圳市迅龙软件有限公司 深圳市迅龙软件有限公司 深圳市迅龙软件有限公司 深圳市迅龙软件有限公司 深圳市迅龙软件有限公司 深圳市迅龙软件有限公司 深圳市迅龙软件有限公司 深圳市迅龙软件有限公司 深圳市迅龙软件有限公司 深圳市迅龙软件有限公司 深圳市迅龙软件有限公司

Xunlong Software Co.,Limited

CARD-USB-DEBUG-EXT26-HDMI

# Differential pairs Z0= 100 ohm

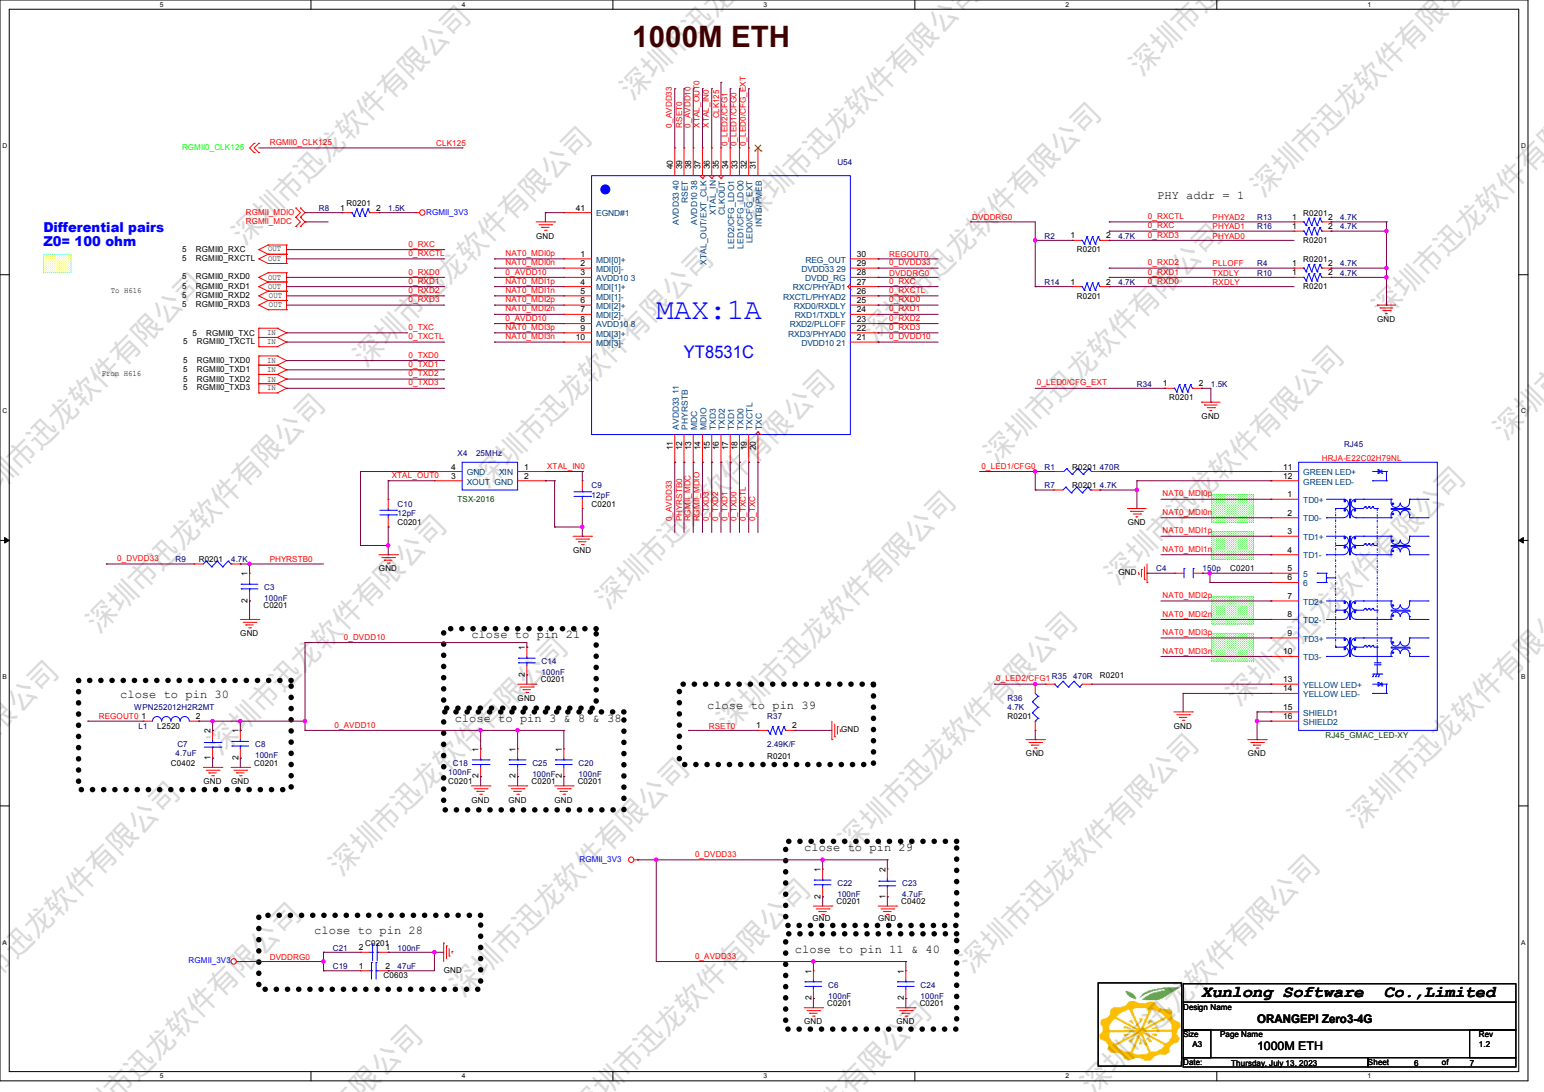
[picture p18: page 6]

深圳市迅龙软件有限公司 深圳市迅龙软件有限公司 深圳市迅龙软件有限公司 深圳市迅龙软件有限公司 深圳市迅龙软件有限公司 深圳市迅龙软件有限公司 深圳市迅龙软件有限公司 深圳市迅龙软件有限公司 深圳市迅龙软件有限公司 深圳市迅龙软件有限公司 深圳市迅龙软件有限公司 深圳市迅龙软件有限公司 深圳市迅龙软件有限公司 深圳市迅龙软件有限公司 深圳市迅龙软件有限公司 深圳市迅龙软件有限公司 深圳市迅龙软件有限公司 深圳市迅龙软件有限公司 深圳市迅龙软件有限公司 深圳市迅龙软件有限公司 深圳市迅龙软件有限公司 深圳市迅龙软件有限公司 深圳市迅龙软件有限公司 深圳市迅龙软件有限公司 深圳市迅龙软件有限公司 深圳市迅龙软件有限公司 深圳市迅龙软件有限公司 深圳市迅龙软件有限公司 深圳市迅龙软件有限公司 深圳市迅龙软件有限公司 深圳市迅龙软件有限公司 深圳市迅龙软件有限公司 深圳市迅龙软件有限公司 深圳市迅龙软件有限公司 深圳市迅龙软件有限公司 深圳市迅龙软件有限公司 深圳市迅龙软件有限公司 深圳市迅龙软件有限公司 深圳市迅龙软件有限公司 深圳市迅龙软件有限公司

Xunlong Software Co.,Limited

D | D

### 50Ω,TOP参考LAYER3

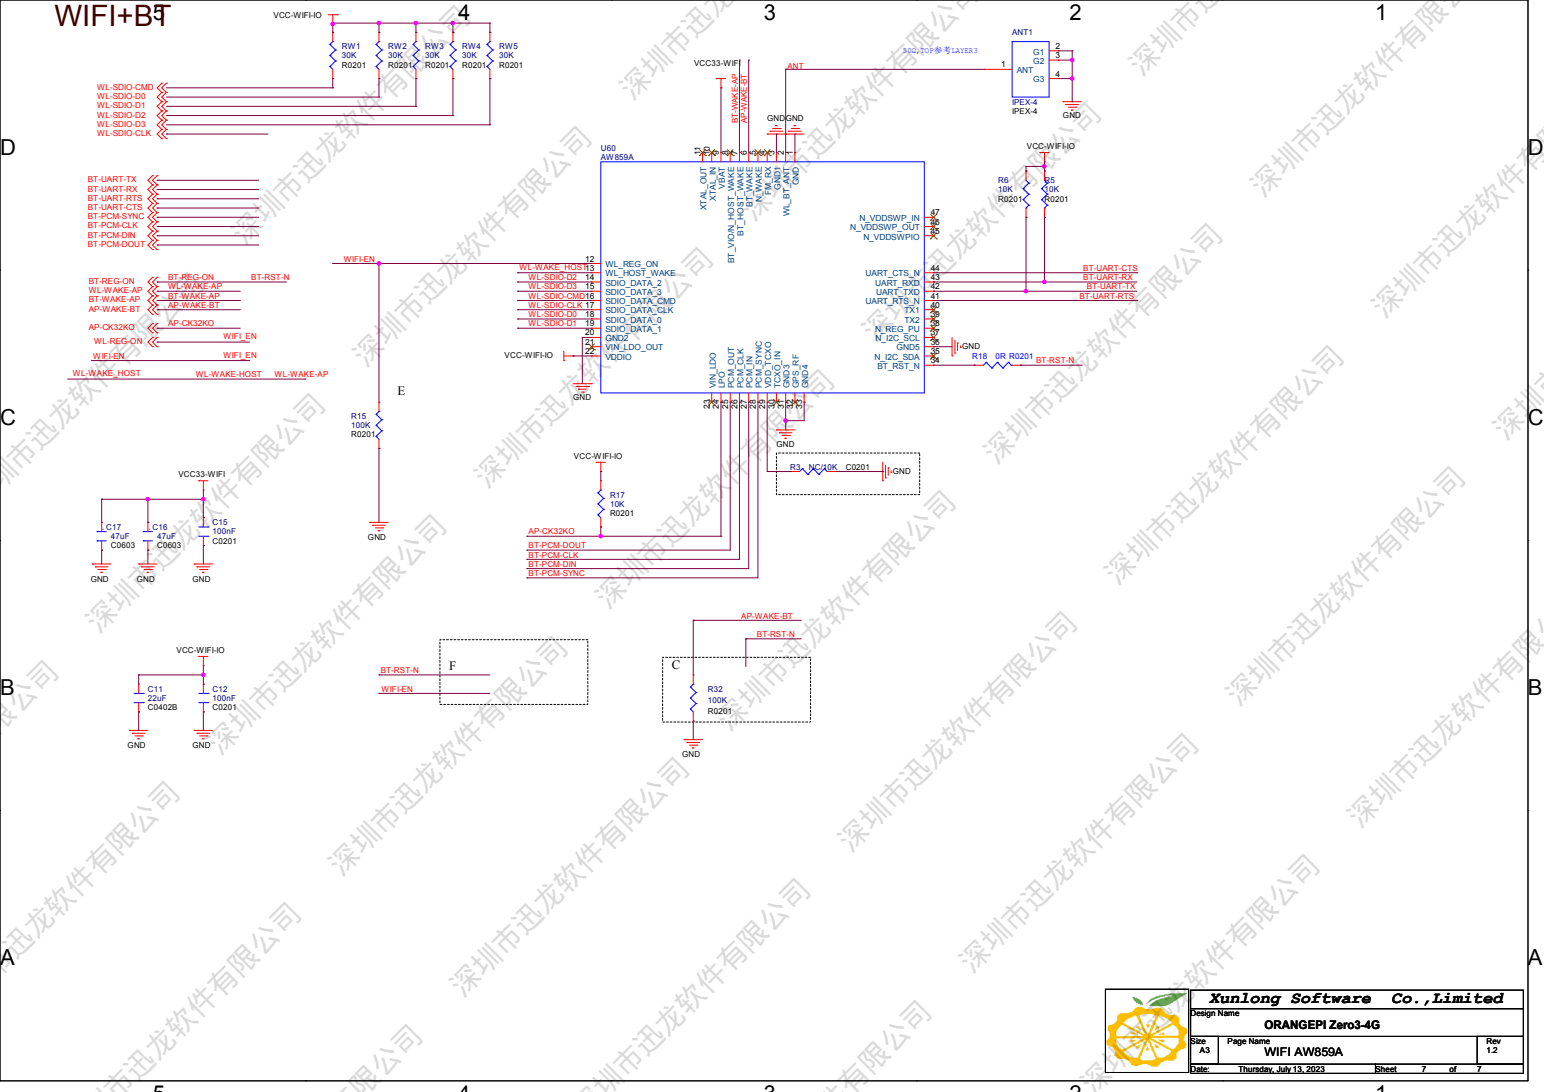
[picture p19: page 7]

深圳市迅龙软件有限公司 深圳市迅龙软件有限公司 深圳市迅龙软件有限公司 深圳市迅龙软件有限公司 深圳市迅龙软件有限公司 深圳市迅龙软件有限公司 深圳市迅龙软件有限公司 深圳市迅龙软件有限公司 深圳市迅龙软件有限公司 深圳市迅龙软件有限公司 深圳市迅龙软件有限公司 深圳市迅龙软件有限公司 深圳市迅龙软件有限公司 深圳市迅龙软件有限公司 深圳市迅龙软件有限公司 深圳市迅龙软件有限公司 深圳市迅龙软件有限公司 深圳市迅龙软件有限公司 深圳市迅龙软件有限公司 深圳市迅龙软件有限公司 深圳市迅龙软件有限公司 深圳市迅龙软件有限公司 深圳市迅龙软件有限公司 深圳市迅龙软件有限公司 深圳市迅龙软件有限公司 深圳市迅龙软件有限公司 深圳市迅龙软件有限公司 深圳市迅龙软件有限公司 深圳市迅龙软件有限公司 深圳市迅龙软件有限公司 深圳市迅龙软件有限公司 深圳市迅龙软件有限公司 深圳市迅龙软件有限公司 深圳市迅龙软件有限公司 深圳市迅龙软件有限公司 深圳市迅龙软件有限公司 深圳市迅龙软件有限公司 深圳市迅龙软件有限公司 深圳市迅龙软件有限公司 深圳市迅龙软件有限公司

Xunlong Software Co.,Limited

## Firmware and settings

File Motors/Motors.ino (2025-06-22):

#include <HardwareSerial.h>
#include <Arduino.h>
#include <Wire.h>

#define CMD_LEFT_FORWARD 0
#define CMD_LEFT_BACKWARD 1
#define CMD_RIGHT_FORWARD 2
#define CMD_RIGHT_BACKWARD 3
#define CMD_LEFT_STOP 4
#define CMD_RIGHT_STOP 5
#define CMD_STOP_MOTORS 6

#define TICKS_IN_CYCLE 233
#define RIGHT_H1_PIN 2
#define RIGHT_H2_PIN 3
#define LEFT_H1_PIN 4
#define LEFT_H2_PIN 12
#define TICKS_IN_METER 0.94 / 1000
// 1058 1041 1035 1072
#define LEFT_TICKS_IN_METER 1.052 / 1000
// 1059 1047 1047 1056
#define RIGHT_TICKS_IN_METER 1.051 / 1000
#define STBY 11

const bool motorsEnabled = true;

// Пины для первого двигателя (Motor A, left)
const int in1 = 5;
const int in2 = 6;
const int enA = 9;

// Пины для второго двигателя (Motor B, right)
const int in3 = 7;
const int in4 = 8;
const int enB = 10;

struct Command
{
  uint8_t cmd;
  uint8_t value;
};

struct SensorData
{
  uint32_t timestamp;
  float left_odometry;
  float right_odometry;
  long left_ticks;
  long right_ticks;
  bool left_h2_state;
  bool right_h2_state;
  bool left_flag;
  bool right_flag;
};

bool left_flag = false;
bool right_flag = false;
bool left_h2_state = false;
bool right_h2_state = false;
long left_ticks = 0;
long right_ticks = 0;

long t = millis();
float odomLeft = 0.0;
float odomRight = 0.0;

void handleCommand(Command cmd)
{
  switch (cmd.cmd)
  {
  case CMD_LEFT_FORWARD:
    moveLeftForward(cmd.value);
    break;
  case CMD_LEFT_BACKWARD:
    moveLeftBackward(cmd.value);
    break;
  case CMD_RIGHT_FORWARD:
    moveRightForward(cmd.value);
    break;
  case CMD_RIGHT_BACKWARD:
    moveRightBackward(cmd.value);
    break;
  case CMD_LEFT_STOP:
    stopLeftMotor();
    break;
  case CMD_RIGHT_STOP:
    stopRightMotor();
    break;
  case CMD_STOP_MOTORS:
    stopMotors();
    break;
  default:
    break;
  }
}

void moveRightForward(int speed)
{
  if (!motorsEnabled)
    return;

  digitalWrite(in1, HIGH);
  digitalWrite(in2, LOW);
  analogWrite(enA, speed);
}

void moveRightBackward(int speed)
{
  if (!motorsEnabled)
    return;

  digitalWrite(in1, LOW);
  digitalWrite(in2, HIGH);
  analogWrite(enA, speed);
}

void moveLeftForward(int speed)
{
  if (!motorsEnabled)
    return;

  digitalWrite(in3, LOW);
  digitalWrite(in4, HIGH);
  analogWrite(enB, speed);
}

void moveLeftBackward(int speed)
{
  if (!motorsEnabled)
    return;

  digitalWrite(in3, HIGH);
  digitalWrite(in4, LOW);
  analogWrite(enB, speed);
}

void stopRightMotor()
{
  if (!motorsEnabled)
    return;

  digitalWrite(in1, LOW);
  digitalWrite(in2, LOW);
  analogWrite(enA, 0);
}

void stopLeftMotor()
{
  if (!motorsEnabled)
    return;

  digitalWrite(in3, LOW);
  digitalWrite(in4, LOW);
  analogWrite(enB, 0);
}

void stopMotors()
{
  stopLeftMotor();
  stopRightMotor();
}

float updateLeftOdometry()
{
  bool state = digitalRead(LEFT_H1_PIN);
  if (state && !left_flag)
  { // фронт LOW-HIGH
    left_flag = true;
  }
  if (!state && left_flag)
  { // фронт HIGH-LOW
    left_flag = false;
  }

  bool new_h2_state = digitalRead(LEFT_H2_PIN);
  if (state && !left_h2_state && new_h2_state)
  {
    left_ticks++;
  }

  if (state && left_h2_state && !new_h2_state)
  {
    left_ticks--;
  }

  left_h2_state = new_h2_state;

  return left_ticks * TICKS_IN_METER;

  // 233 ticks == 1 оборот - замер
  // 69.60*3.14= 218.54 mm длина окружности - рассчёт
  // 1 tick == 218.54/2s33 = 0.94 mm
}

float updateRightOdometry()
{
  bool state = digitalRead(RIGHT_H1_PIN);
  if (state && !right_flag)
  { // фронт LOW-HIGH
    right_flag = true;
  }
  if (!state && right_flag)
  { // фронт HIGH-LOW
    right_flag = false;
  }

  bool new_h2_state = digitalRead(RIGHT_H2_PIN);
  if (state && !right_h2_state && new_h2_state)
  {
    right_ticks--;
  }

  if (state && right_h2_state && !new_h2_state)
  {
    right_ticks++;
  }

  right_h2_state = new_h2_state;

  return right_ticks * TICKS_IN_METER;

  // 233 ticks == 1 оборот - замер
  // 69.60*3.14= 218.54 mm длина окружности - рассчёт
  // 1 tick == 218.54/2s33 = 0.94 mm
}

void setup()
{
  Serial.begin(115200);

  left_h2_state = digitalRead(LEFT_H2_PIN);
  right_h2_state = digitalRead(RIGHT_H2_PIN);

  pinMode(in1, OUTPUT);
  pinMode(in2, OUTPUT);
  pinMode(enA, OUTPUT);

  pinMode(in3, OUTPUT);
  pinMode(in4, OUTPUT);
  pinMode(enB, OUTPUT);

  pinMode(STBY, OUTPUT);

  stopMotors();

  digitalWrite(STBY, HIGH);
}

void sendSensorData(SensorData sensorData)
{
  Serial.write((byte *)&sensorData, sizeof(SensorData));
}

void loop()
{
  if (Serial.available() >= sizeof(Command))
  {
    Command receivedCommand;
    Serial.readBytes((byte *)&receivedCommand, sizeof(Command));
    handleCommand(receivedCommand);
  }

  odomLeft = updateLeftOdometry();
  odomRight = updateRightOdometry();

  if (millis() - t > 50)
  {
    t = millis();

    SensorData sensorData;
    sensorData.timestamp = millis();
    sensorData.left_odometry = odomLeft;
    sensorData.right_odometry = odomRight;
    sensorData.left_ticks = left_ticks;
    sensorData.right_ticks = right_ticks;
    sensorData.left_h2_state = left_h2_state;
    sensorData.right_h2_state = right_h2_state;
    sensorData.left_flag = left_flag;
    sensorData.right_flag = right_flag;

    sendSensorData(sensorData);
  }
}

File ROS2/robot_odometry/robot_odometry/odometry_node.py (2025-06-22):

#!/usr/bin/env python3

import rclpy
from rclpy.node import Node
from nav_msgs.msg import Odometry
from geometry_msgs.msg import Quaternion, TransformStamped, Twist
from tf2_ros import TransformBroadcaster
import serial
import struct
import math
import time

# Команды для моторов (из Motors.ino)
CMD_LEFT_FORWARD = 0
CMD_LEFT_BACKWARD = 1
CMD_RIGHT_FORWARD = 2
CMD_RIGHT_BACKWARD = 3
CMD_LEFT_STOP = 4
CMD_RIGHT_STOP = 5
CMD_STOP_MOTORS = 6

# Форматы структур данных
COMMAND_FORMAT = '<BB'  # struct Command: uint8_t cmd, uint8_t value

class OdometryNode(Node):
    def __init__(self):
        super().__init__('odometry_node')
        # Параметры
        self.declare_parameter('serial_port', '/dev/ttyUSB0')
        self.declare_parameter('baud_rate', 115200)
        self.declare_parameter('wheel_base', 0.265)  # Расстояние между колесами
        self.declare_parameter('max_linear', 0.5)  # м/с
        self.declare_parameter('max_angular', 1.57)  # рад/с
        self.declare_parameter('max_motor_speed', 255)  # максимальная скорость мотора PWM
        self.declare_parameter('simulation_mode', False)
        
        self.simulation_mode = self.get_parameter('simulation_mode').value
        
        if not self.simulation_mode:
            port = self.get_parameter('serial_port').value
            baud = self.get_parameter('baud_rate').value
            
            try:
                self.ser = serial.Serial(port, baud, timeout=0.1)
                time.sleep(2)  # Ждем инициализации Arduino
                self.get_logger().info(f"Connected to Arduino on {port}")
            except Exception as e:
                self.get_logger().error(f"Failed to connect to Arduino: {e}")
                raise
        else:
            self.ser = None
            self.get_logger().info("Running in simulation mode (no Arduino connection)")
        
        # Формат структуры SensorData из Motors.ino
        # struct SensorData: uint32_t timestamp, float left_odometry, float right_odometry, 
        #                   long left_ticks, long right_ticks, bool left_h2_state, 
        #                   bool right_h2_state, bool left_flag, bool right_flag
        self.sensor_data_format = '<Iffll????'
        self.sensor_data_size = struct.calcsize(self.sensor_data_format)
        
        # Инициализация переменных одометрии
        self.left_prev = 0.0
        self.right_prev = 0.0
        self.x = 0.0
        self.y = 0.0
        self.theta = 0.0
        self.last_time = self.get_clock().now()
        
        # ROS интерфейсы
        self.odom_pub = self.create_publisher(Odometry, 'odom', 10)
        self.tf_broadcaster = TransformBroadcaster(self)
        
        # Подписка на команды teleop
        self.cmd_vel_sub = self.create_subscription(
            Twist,
            'cmd_vel',
            self.cmd_vel_callback,
            10)
        
        # Таймер для чтения данных
        self.create_timer(0.05, self.read_serial)  # 20 Гц
    
    def send_command(self, cmd, value):
        """Отправка команды мотору через бинарный протокол"""
        if self.simulation_mode:
            cmd_names = {
                CMD_LEFT_FORWARD: "LEFT_FORWARD",
                CMD_LEFT_BACKWARD: "LEFT_BACKWARD", 
                CMD_RIGHT_FORWARD: "RIGHT_FORWARD",
                CMD_RIGHT_BACKWARD: "RIGHT_BACKWARD",
                CMD_LEFT_STOP: "LEFT_STOP",
                CMD_RIGHT_STOP: "RIGHT_STOP",
                CMD_STOP_MOTORS: "STOP_MOTORS"
            }
            self.get_logger().info(f"[SIM] Motor command: {cmd_names.get(cmd, f'CMD_{cmd}')} = {value}")
            return True
            
        if not self.ser or not self.ser.is_open:
            self.get_logger().error("Serial порт не открыт!")
            return False
        
        try:
            packed_command = struct.pack(COMMAND_FORMAT, cmd, value)
            self.ser.write(packed_command)
            return True
        except Exception as e:
            self.get_logger().error(f"Ошибка отправки команды: {e}")
            return False

    def cmd_vel_callback(self, msg):
        """Обработка команд телеоперации"""
        # Параметры
        wheel_base = self.get_parameter('wheel_base').value
        max_linear = self.get_parameter('max_linear').value
        max_angular = self.get_parameter('max_angular').value
        max_motor_speed = self.get_parameter('max_motor_speed').value
        
        # Ограничение скоростей
        linear = max(min(msg.linear.x, max_linear), -max_linear)
        angular = max(min(msg.angular.z, max_angular), -max_angular)
        
        # Преобразование в скорости колес (дифференциальный привод)
        left = linear - (angular * wheel_base) / 2.0
        right = linear + (angular * wheel_base) / 2.0
        
        # Нормализация скоростей
        max_speed = max(abs(left), abs(right))
        if max_speed > max_linear:
            left = left * max_linear / max_speed
            right = right * max_linear / max_speed
        
        # Преобразование в PWM значения (0-255)
        left_pwm = int(abs(left) * max_motor_speed / max_linear)
        right_pwm = int(abs(right) * max_motor_speed / max_linear)
        
        # Ограничение PWM значений
        left_pwm = max(0, min(255, left_pwm))
        right_pwm = max(0, min(255, right_pwm))
        
        # Определение направления и отправка команд
        if left == 0:
            self.send_command(CMD_LEFT_STOP, 0)
        elif left > 0:
            self.send_command(CMD_LEFT_FORWARD, left_pwm)
        else:
            self.send_command(CMD_LEFT_BACKWARD, left_pwm)
            
        if right == 0:
            self.send_command(CMD_RIGHT_STOP, 0)
        elif right > 0:
            self.send_command(CMD_RIGHT_FORWARD, right_pwm)
        else:
            self.send_command(CMD_RIGHT_BACKWARD, right_pwm)

    def read_serial(self):
        """Чтение бинарных данных от Arduino"""
        if not self.simulation_mode and self.ser.in_waiting >= self.sensor_data_size:
            try:
                data = self.ser.read(self.sensor_data_size)
                if len(data) == self.sensor_data_size:
                    # Распаковка структуры SensorData
                    unpacked = struct.unpack(self.sensor_data_format, data)
                    timestamp, left_odo, right_odo, left_ticks, right_ticks, left_h2, right_h2, left_flag, right_flag = unpacked
                    
                    # Обрабатываем одометрию (расстояния уже готовые в метрах)
                    self.process_odometry(left_odo, right_odo)
                    
            except struct.error as e:
                self.get_logger().error(f"Struct unpack error: {e}")
            except Exception as e:
                self.get_logger().error(f"Serial read error: {e}")
        elif self.simulation_mode:
            # В режиме симуляции отправляем фиктивные данные одометрии
            self.process_odometry(0.0, 0.0)
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

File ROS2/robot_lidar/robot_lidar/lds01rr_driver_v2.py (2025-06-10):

#!/usr/bin/env python3
"""
LDS01RR Lidar Driver v2 for ROS2
Based on official Roborock Cullinan documentation
Supports 0xAA (info) and 0xFA (measurement) packet headers
"""

import serial
import struct
import math
from collections import deque
from enum import Enum
from typing import List, Optional, Dict, Tuple
import time


class PacketState(Enum):
    SYNC = 0
    INFO_PACKET = 1
    INFO_ESCAPE = 2
    MEAS_PACKET = 3


class MeasurementData:
    def __init__(self):
        self.distance_mm: int = 0
        self.intensity: int = 0
        self.angle_deg: float = 0.0
        self.quality: int = 0
        self.invalid_flag: bool = False
        self.strength_warning: bool = False


class LDS01RRDriverV2:
    def __init__(self, serial_port: str, baud_rate: int = 115200):
        """
        Initialize the LDS01RR driver v2
        
        Args:
            serial_port: Serial port device (e.g., '/dev/ttyS5')
            baud_rate: Baud rate for serial communication
        """
        self.serial_port_name = serial_port
        self.baud_rate = baud_rate
        self.serial_port: Optional[serial.Serial] = None
        self.shutting_down = False
        
        # Packet parsing state
        self.state = PacketState.SYNC
        self.packet_buffer = bytearray()
        self.packet_count = 0
        
        # Measurement data storage
        self.scan_data = []
        self.current_scan_complete = False
        
        # Speed calculation
        self.speed_sum = 0
        self.packet_cnt = 0
        self.last_angle = None
        
        # Constants according to documentation
        self.INFO_PACKET_SIZE = 85  # 84 + 1 sync byte
        self.MEAS_PACKET_SIZE = 22  # 22 bytes total
        
        # Initialize serial connection
        self._connect()
    
    def _connect(self):
        """Connect to the serial port"""
        try:
            self.serial_port = serial.Serial(
                port=self.serial_port_name,
                baudrate=self.baud_rate,
                timeout=1.0,
                bytesize=serial.EIGHTBITS,
                parity=serial.PARITY_NONE,
                stopbits=serial.STOPBITS_ONE
            )
            print(f"Connected to {self.serial_port_name} at {self.baud_rate} baud")
        except serial.SerialException as e:
            raise RuntimeError(f"Failed to connect to {self.serial_port_name}: {e}")
    
    def disconnect(self):
        """Disconnect from the serial port"""
        self.shutting_down = True
        if self.serial_port and self.serial_port.is_open:
            self.serial_port.close()
    
    def poll(self) -> Optional[List[MeasurementData]]:
        """
        Poll the lidar for new scan data
        
        Returns:
            List of MeasurementData objects if a complete scan is received, None otherwise
        """
        if not self.serial_port or not self.serial_port.is_open:
            print("DEBUG: Serial port not available or not open")
            return None
        
        try:
            data = self.serial_port.read(1)
            if len(data) == 0:
                return None
            
            byte_val = data[0]
            packet_ready = self._parse_byte(byte_val)
            
            if packet_ready == 0:  # Measurement packet processed successfully
                if self.current_scan_complete:
                    print(f"DEBUG: Scan complete! Returning {len(self.scan_data)} measurements")
                    result = list(self.scan_data)
                    self.scan_data.clear()
                    self.current_scan_complete = False
                    return result
                        
        except serial.SerialException as e:
            print(f"Serial error: {e}")
            return None
        
        return None
    
    def _parse_byte(self, byte_val: int) -> int:
        """
        Parse incoming byte according to LDS.c protocol from documentation
        
        Args:
            byte_val: Received byte
            
        Returns:
            0 if packet processed successfully, 1 if pending, -1 if error
        """
        if self.state == PacketState.SYNC:
            if byte_val == 0xAA:  # LDS information packet
                print("DEBUG: Info packet started (0xAA)")
                self.packet_buffer = bytearray([0xAA])
                self.packet_count = 1
                self.state = PacketState.INFO_PACKET
            elif byte_val == 0xFA:  # LDS measurement packet
                self.packet_buffer = bytearray([0xFA])
                self.packet_count = 1
                self.state = PacketState.MEAS_PACKET
            else:
                # Synchronization loss - ignore byte
                pass
                
        elif self.state == PacketState.INFO_PACKET:
            if byte_val != 0xAA:
                if byte_val != 0xA9:  # Normal data byte
                    self.packet_buffer.append(byte_val)
                    self.packet_count += 1
                    
                    if self.packet_count >= self.INFO_PACKET_SIZE:
                        # Full information packet received
                        print(f"DEBUG: Full info packet received ({self.packet_count} bytes)")
                        self.state = PacketState.SYNC
                        if self._check_info_packet():
                            self._process_info_packet()
                            return 0
                        else:
                            print("DEBUG: Info packet checksum failed")
                            return -1
                else:  # 0xA9 escape character
                    self.packet_buffer.append(0xA9)
                    # Don't increment packet_count yet
                    self.state = PacketState.INFO_ESCAPE
            else:  # Unexpected 0xAA
                self.packet_buffer.append(0xAA)
                self.packet_count += 1
                print("Unexpected 0xAA in info packet!")
                self.state = PacketState.SYNC
                
        elif self.state == PacketState.INFO_ESCAPE:
            if byte_val == 0x00:  # 0xA900 - represents 0xA9
                self.packet_count += 1
            elif byte_val == 0x01:  # 0xA901 - represents 0xAA
                self.packet_buffer[-1] = 0xAA  # Replace last 0xA9 with 0xAA
                self.packet_count += 1
            else:  # Error
                self.packet_buffer.append(byte_val)
                self.packet_count += 1
                print("Error in escape sequence")
                self.state = PacketState.SYNC
                return -1
            
            # Check if packet is complete
            if self.packet_count >= self.INFO_PACKET_SIZE:
                self.state = PacketState.SYNC
                if self._check_info_packet():
                    self._process_info_packet()
                    return 0
                else:
                    return -1
            else:
                self.state = PacketState.INFO_PACKET
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

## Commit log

2025-06-05 Добавлено руководство по удалённому запуску системы через SSH в документацию пакетов ROS2
2025-06-08 Добавлен драйвер для лидара LDS01RR, включая документацию, скрипты установки и тестирования. Обновлены файлы сборки и диагностики для поддержки нового пакета. Расширена структура проекта в README.md.
    [крепёж заднего колеса.FCStd]
2025-06-10 Добавлены Docker контейнеры для всех ROS2 нод робота, включая конфигурации для Discovery Server и основные ноды. Созданы Dockerfile и docker-compose файлы для каждого пакета, а также обновлена докуме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
2025-06-13 Обновлены Dockerfile и конфигурации для всех ROS2 нод, заменив базовый образ на ros:humble. Добавлены скрипты entrypoint для каждой ноды. Создан новый скрипт для загрузки и сборки пакетов на удалённо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
    [крепёж аккум-Body.stl, крепёж аккум.FCStd]
2025-06-13 Добавлено руководство по контейнеризации ROS2 пакетов с использованием Docker в README.md. Обновлены разделы о запуске системы и установке, добавлены детали о Docker контейнерах для каждого пакета, в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
2025-06-15 Добавлены файлы конфигурации FastDDS для всех ROS2 нод, обновлены Dockerfile и entrypoint скрипты для поддержки новой конфигурации. Создан скрипт для автоматического копирования и обновления конфигур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
2025-06-15 Переименован пакет лидара с `lds01rr_lidar_ros2` на `robot_lidar`. Обновлены все соответствующие файлы конфигурации, Dockerfile и скрипты для поддержки нового имени пакета. Удалены старые файлы и доб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
2025-06-15 Добавлены новые разделы в README.md для работы с камерой и интеграции тестирования в ROS2. Создан новый файл test_integration.py для проверки взаимодействия с одометрией и управления движением. Обнов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
2025-06-16 Добавлены новые скрипты gui_host.sh и test_motors.py для управления камерой и тестирования моторов. Обновлен скрипт run_robot.sh для поддержки запуска камеры с новыми параметрами. Расширены параметры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
2025-06-16 Обновлен README.md с новыми инструкциями по установке зависимостей для Python 3 и Cyclone DDS, а также добавлены команды для проверки работы узлов. Изменен скрипт сборки на роботе для поддержки ROS2 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
2025-06-16 Добавлены новые инструкции по установке arduino-cli в README.md. Обновлен скрипт compile.sh для Motors и Sensors с обработкой ошибок. Созданы новые скрипты test_motors.py и test_sensors.py для тестир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
2025-06-16 Обновлен README.md с новыми инструкциями по установке и настройке SLAM. Удален устаревший файл test_motors.py. Исправлена ошибка в обработке данных одометрии в odometry_node.py.
    [odometry_node.py, test_motors.py]
2025-06-22 Обновлены определения переменных одометрии в Motors.ino для использования типа long. Добавлены новые параметры LEFT_TICKS_IN_METER и RIGHT_TICKS_IN_METER. Создан новый скрипт test_odometry.py для тес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
